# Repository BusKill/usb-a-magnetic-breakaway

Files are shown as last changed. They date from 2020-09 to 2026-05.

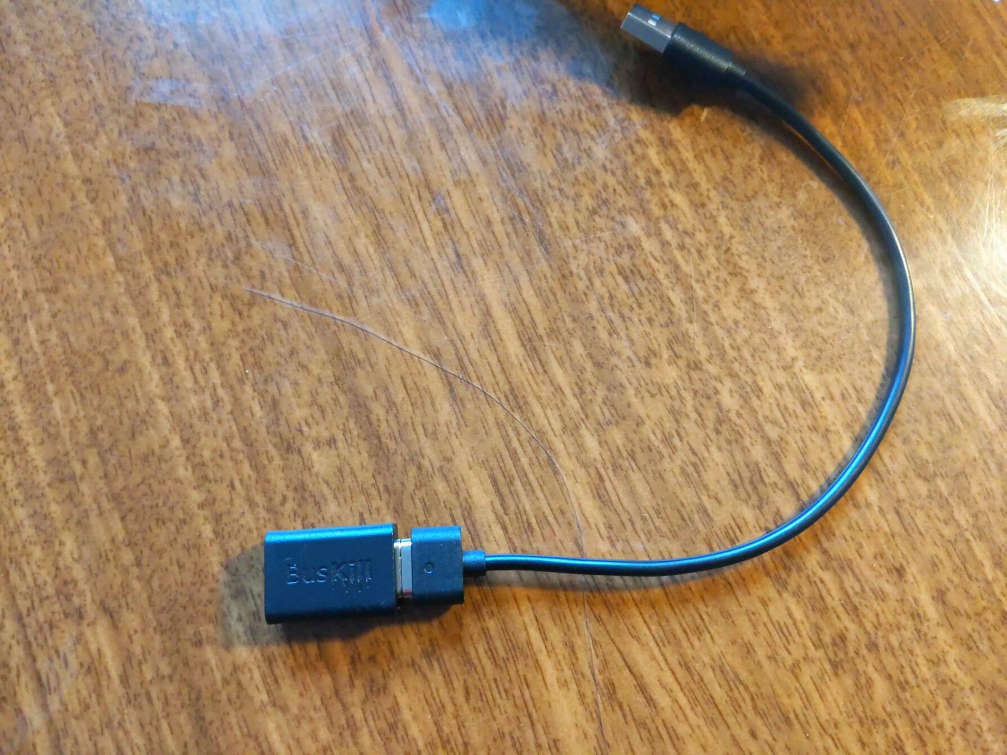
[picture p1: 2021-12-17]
supplier/shenzen_qh_industrial_co/2021-12-04/202112_buskill_sample1a.jpg

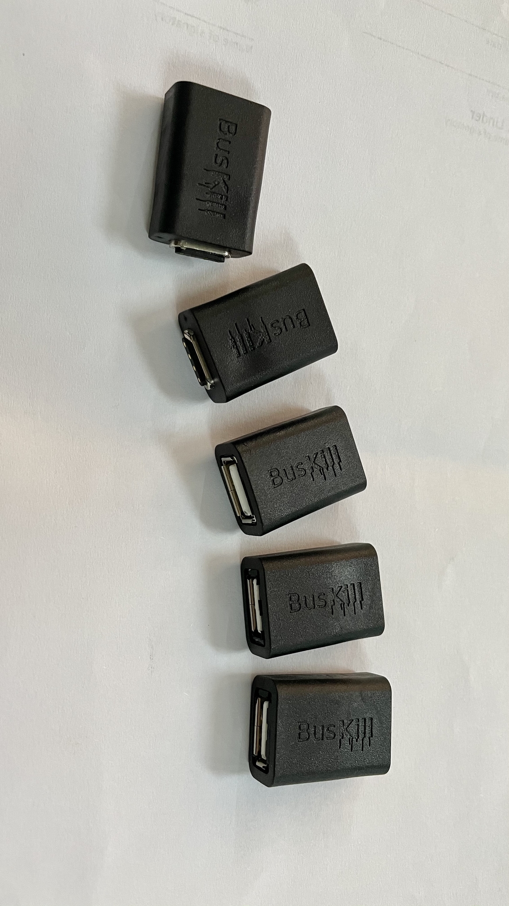
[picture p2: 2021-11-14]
supplier/shenzen_qh_industrial_co/2021-11-14/buskill_samples_001.jpg

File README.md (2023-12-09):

# usb-a-magnetic-breakaway

This repo is for documenting and providing the design requirements for an open-source USB-A magnetic breakaway connector used in the BusKill laptop kill cord. This project is a Work In Progress and it welcomes contributors. 

Please see https://github.com/BusKill/usb-a-magnetic-breakaway/issues/2 for a history of the development so far and the latest news on what people are currently working on with regard to the 3D printed version of the case. 

## For More Information

* What is BusKill? https://tech.michaelaltfield.net/2020/01/02/buskill-laptop-kill-cord-dead-man-switch/
* BusKill YouTube https://www.youtube.com/channel/UC5Njxb027m2OmrocrH33oew
* BusKill Crowdsupply https://www.crowdsupply.com/alt-shift/buskill
* BusKill Open Collective https://opencollective.com/buskill
* BusKill Documentation https://docs.buskill.in

If you create your own version, please create a folder and add your assets to the folder. Feel free to document your section content in this Readme following the style by which we have documented ours.

##  What's New?

* Updates to goldfishlaser Version: She is currently filming Part 2 ofthe assembly instructions and working on the final written documentation. Part 1 Video Assembly Instructions: https://youtu.be/HxwEmIUqQ7w?si=xajbAuSA-TxbAlxz

## What's in this Repo?

This repo contains information about the project, CAD files for two versions of the project, and information about a supplier version of the cable. 

### Glossary
To reference our technical terminology check out [glossary.md](https://github.com/BusKill/usb-a-magnetic-breakaway/blob/3cc552533db1436cacee31b77e96ae590389fd92/Glossary.md)

### goldfishlaser Version

This directory contains files for a version built in OpenSCAD by goldfishlaser. It contains documented 3D print files (SCAD and STL), Bill of Materials, and more. See issue#2 for more details.

goldfishlaser Version

Part 1 Video Assembly Instructions: https://youtu.be/HxwEmIUqQ7w?si=xajbAuSA-TxbAlxz
Prototype Assembly Instructions: https://crashxblossom.wordpress.com/2023/07/04/exciting-milestone-in-buskill-usb-a-magnetic-release-open-hardware-project/

#### CAD Files

Directory contains CAD files for the magnetic breakway case if you want to edit the files. *(in development)*

#### Print files

Directory contains 3D print files for the magnetic breakaway case. *(in development)*

#### Engineering drawings

Directory contains engineering drawings for the magnets which you can provide to a manufacturer for the purpose of ordering the magnets for the magnetic breakway.

#### Magnet_and_PP_Vendor_List.ods

File contains a list of manufacturers that sell magnets, pogo pins, and pogo receptors. 

### Leoheck CAD files
(3D printable case, Work In Progress)
This directory contains files are for a version built in FreeCAD by leoheck.  This version uses Yoosoo spring pressure pogo pins,uses aluminium can for pin contacts, and has pressfit voids for cube magnets. This version contains a female USB port. See issue#2 for more details.



## Supplier Version

image of supplier version

Please see https://github.com/BusKill/usb-a-magnetic-breakaway/issues/4 for history on the development of the Supplier Version. 

### digitalAssets

Digital assets relating to supplier version of the BusKill breakaway

### supplier

Other assets relating to the supplier version of the BusKill breakaway

## Contributing

Please see [Contributing to BusKill](https://docs.buskill.in/buskill-app/en/stable/contributing.html) to learn how you can help the BusKill project.

## Attribution

Thank you to the countless individuals and other open-source projects that have contributed to to the BusKill project!

## Press

As seen on PCMag, Forbes, ZDNet, & Tom's Hardware.

## Contact

To contact us via email, please visit:

    https://www.buskill.in/contact/

## License

The contents of this repo are dual-licensed. All code is GPLv3 and all other content is CC-BY-SA.

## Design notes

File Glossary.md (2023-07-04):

# List of Terms
1. [Breakaway End](#Breakway-End)
2. [BusKill Cable](#BusKill-Cable)
3. [BusKill Software](#BusKill-Software)
4. [Jig](#Jig)
5. [Magnetic_Coupler](#Magnetic-Coupler)
6. [Magnetic Release Cord](#Magnetic-Release-Cord)
7. [Pogo Contacts](#Pogo-Contacts)
8. [Pogo Pin](#Pogo-Pin)
9. [Pogo Contact](#Pogo-Contact)
10. [Release End](#Release-End)
11. [USB A](#USB-A)
12. [USB Ejection Event](#USB-Ejection-Event)
13. [USB Insertion Event](#USB-Insertion-Event)

# Breakaway End 
The Magnetic Coupler has two parts. The Breakway end is the part of the coupler that would separate from the laptop, it terminates the cord that is attached to the user. 

# BusKill Cable 
Used to refer to the assembly of a USB, USB Extender Cord, and Magnetic Coupler with a laptop installed and running BusKill software. 

# BusKill Software 
A program that you can install on Linux, MacOS, or Windows that allows you to set up a trigger that occurs with a USB Ejection Event. The trigger could be locking the screen, shutting down the computer, or something else. 

# Jig
A printed piece that is used to stabilize something during assembly. 

# Magnetic Coupler 
The Magnetic Coupler has two parts, the Breakaway End and the Release End. These two parts contain magnets and contacts. The coupler is designed so that when the magnets are in place, the Pogo Pins and Pogo Receptors contact and transfer signal through the coupler. When the Magnets detach, the Pins and Receptors separate and the signal is disconnected causing a USB ejection event.

# Magnetic Release Cord  
*AKA Magnetic Breakaway Cord* 

All of these terms are used to refer to the assembly of a USB A, USB A Extender Cord, and Magnetic Coupler.

# Pogo Contact 
Contacts refers to either the Pogo Pins or the Pogo Recptors. For the Magnetic Coupler to work, the contacts move the data and power from one end of the magnetic coupler to the other so that the USB drive is connected to the Laptop. They're directly wired into the USB Extender Cord.

# Pogo Pin 
The Pogo Pin is a spring loaded pogo pin. It is soldered to a pin of a USB A port and housed in the Release End of the Magnetic Coupler. When it is in contact with a Pogo Receptor on the end of a USB Extender Cord (housed in Breakaway End of the Coupler), signal 

# Pogo Receptor 
The Pogo Receptor is a conductive contact. It is soldered to the wires of a USB Extender Cord and housed in the Breakway End of the Magnetic Coupler. 

# Release End 
The Magnetic Coupler has two parts. The Release end is the part of the coupler that would remain connected to the laptop, it terminates the cord that ends with the USB that is inside the computer USB port. 

# USB A 
USB A is a type of USB connection. It's the type of connection USB drives use. 

# USB Ejection Event 
What happens when you remove a USB drive from a computer's USB port (or otherwise interrupt the connection, such as with a magnetic coupler) and the computer begins the process of recognizing the connection has terminated.

# USB Extender Cord 
*AKA USB Extension Cable*

The USB Extender Cord is a cord that has a USB female port on one end and a USB at the other end. In the BusKill project, this must necessarily be a Data cord, because the project requires a USB data connection. 

# USB Insertion Event 
What happens when you insert a USB drive into a computer's USB port and the computer begins a process of recognizing the device and establishing a connection.

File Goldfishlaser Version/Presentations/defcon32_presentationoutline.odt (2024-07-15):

BusKill Defcon32 Demo Lab Outline

I. Introduction (2 mins)
  - Who is BusKill?
  - Project Goal
  - Project Rationale
II. Get to know the audience (2 mins)
  - Raise hand if
    - Have ever heard of BusKill
    - Have a 3D printer
    - Use Kali? Use QubesOS? Use Tails?
III. Software Capabilities (5 mins)
  - Lock screen / Shutdown (less than 1 min)
  - Luks Header Shredder (1 min) forensically proven with bulk extractor
  - Qubes
  - Limitations
IV. Hardware Requirements (3 mins)
  - Establishes physical security from computer to person
  - Disconnects usb easily, but not too easily
  - Able to dissemble for inspection
  - Doesn’t block neighboring ports
V. Supplier Version (1 min)
  - Components list
  - Where to find in Repo
VI. 3D-Printed Version (2 mins)
  - Components list
  - Where to find in Repo
  - Demo
VII. Hardware Development History and Philosophy (10 mins)
        - Parametric design in OpenSCAD
        - Milestones
            - Choosing parts (considerations for pogo pins, receptors, usbs)
            - Trying to splice it, frying the USB drives
            - The magnets (hexagonal, Nstrength, disc/cube)
        - Constraints
        - OpenSCAD code tour
VIII. How to help and FAQ (6 mins)
  - Build it
  - Make the case smaller
  - Make assembly easier
  - Identify cheaper and more easily sourced components
  - Make the code more parametric

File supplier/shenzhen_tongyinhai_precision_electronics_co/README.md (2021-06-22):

https://sztyhtech.en.alibaba.com/company_profile.html

    https://sztyhtech.en.alibaba.com/product/60833583652-821299794/2019_New_Product_Frosted_Aluminium_Alloy_Fast_Charging_Magnetic_Adapter_For_Android_Type_C.html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
    https://sztyhtech.en.alibaba.com/product/60835405273-821299794/Tongyinhai_USB_Cable_3_1_Type_C_Male_to_TYpe_C_Female_Magnetic_Adapter.html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
    https://sztyhtech.en.alibaba.com/product/60834397314-821299794/Tongyinhai_New_Product_Aluminum_Alloy_Fast_Charging_Magnetic_Adapter_3_In1_For_Android_Ios_Type_C.html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

See also https://github.com/BusKill/usb-a-magnetic-breakaway/issues/4

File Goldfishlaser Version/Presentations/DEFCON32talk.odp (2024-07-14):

## Open Hardware Design for BusKill Cord

Presented at DEFCON32 Demo Lab by Melanie Allen AKA @goldfishlaser

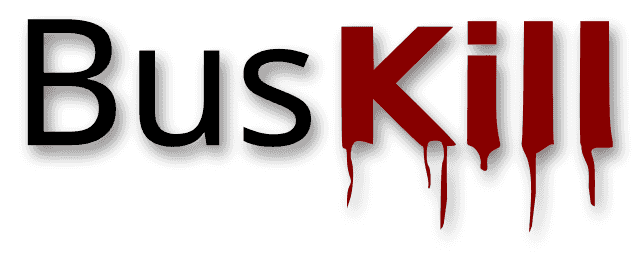
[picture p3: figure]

## Who is ?

Founder

Michael Altfield <michaelaltfield.net>

Lead 3D-Printing Developer

@goldfishlaser

Melanie Allen

<mnallen.net>

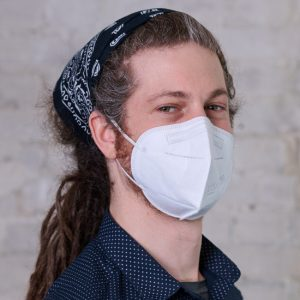
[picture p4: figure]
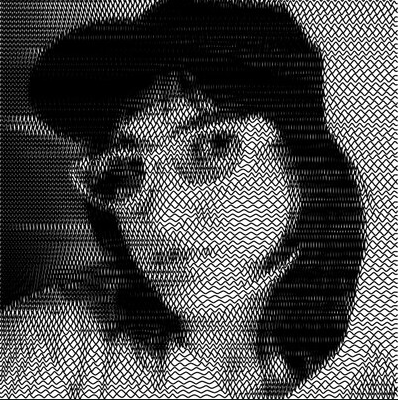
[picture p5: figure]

Contributors (https://docs.buskill.in/buskill-app/en/stable/attribution.html)

Sam <youtube.com/@samxplogs>

Steven Johnson <linkedin.com/in/sj2019/>

Jacob Neplokh <jacobneplokh.com/>

François Marier <fmarier.org/>

Cyberkryption <github.com/cyberkryption>

Links

@BusKill@mastodon.social

https://docs.buskill.in

## Project Goal

- Create a design for BusKill that is suitable for decentralized, home lab manufacture using 3D printing and easily sourced parts to avoid interdiction for high risk individuals such as journalists, activists, and whistleblowers.

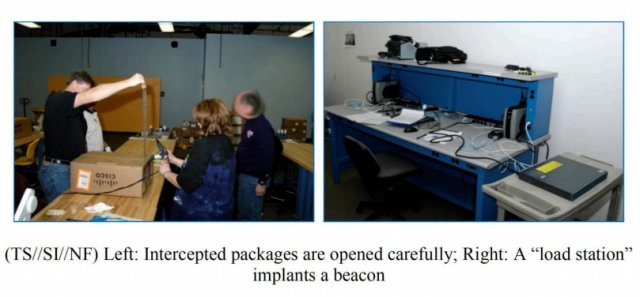
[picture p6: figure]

In 2013, TAO infected 85,000 computers/routers, and they were targeting to increase that to millions

(Source (https://web.archive.org/web/20240625190203/https://www.washingtonpost.com/world/national-security/us-spy-agencies-mounted-231-offensive-cyber-operations-in-20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))

## Project Goal

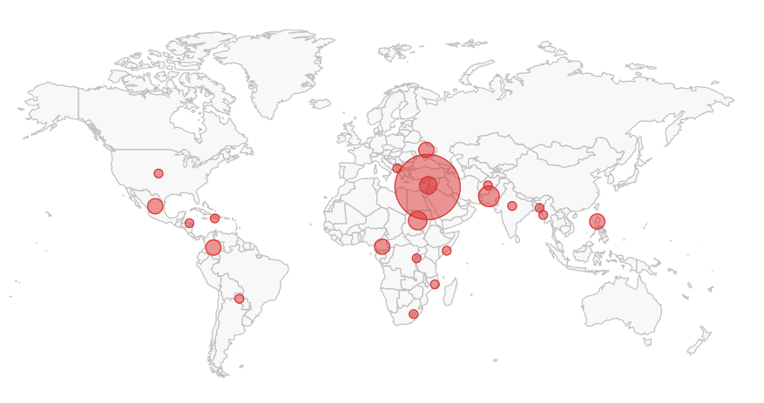
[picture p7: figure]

140 Journalists and Media Workers killed between 2023 and 2024 / Motive Confirmed or Unconfirmed

(Source (https://cpj.org/data/killed/2024/?status=Killed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))

## Purpose

- Allow high risk individuals a method to quickly secure sensitive information when separated from their laptops

## BusKill Software Capabilities

  Lock the computer

perhaps a screencap of Sam's video showing the windows shutdown

## BusKill Software Capabilities

  Shut down the computer

## BusKill Software Capabilities

  Shred your keys

perhaps a hexdump showing random data, or just the featured image from the "luks header shredder" article. Or, if you can do video, the 5.2 second video showing the actual self-destruct (from the article) https://www.buskill.in/luks-self-destruct/

## Qubes

## BusKill Hardware Requirements

- Be able to build in the home
- Be inspectable
- Not block other USB ports
- Separate easily, yet not have false positives

## Manufactured Version

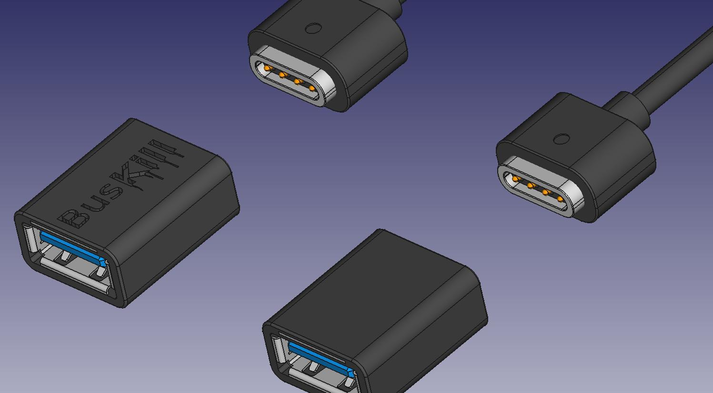
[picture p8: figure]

## 3D-Printed Version Demo

## 3D-Printed BusKill Diagram

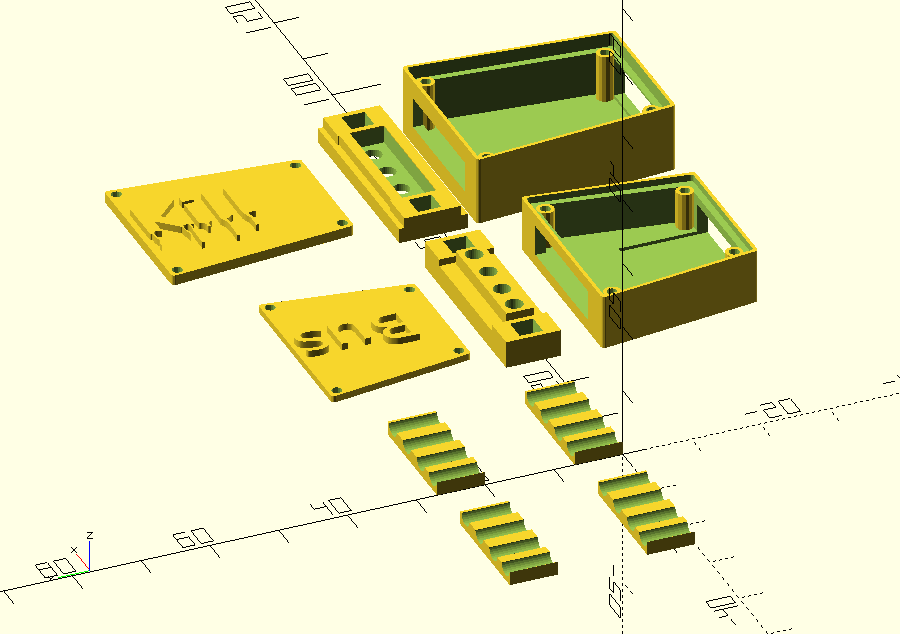
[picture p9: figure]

## Hardware Development Philosophy

- Short history of development
- Link to the repo
- Explain the file and how to edit it

## How you can help – 3D-printing

- Make one
- Improve it
  - The more compact the design, the better
  - The cheaper the design, the better
  - The more parametric the design, the better

## How you can help - Software

- Develop more self-destruct triggers:
  - Veracrypt
  - FileVault
  - Bitlocker

## References

- BusKill web site
- BusKill docs
- BusKill repo
- BusKill USB-A repo
- LUKS shredder blog post

## Questions? Comments?

@BusKill@mastodon.social

https://docs.buskill.in

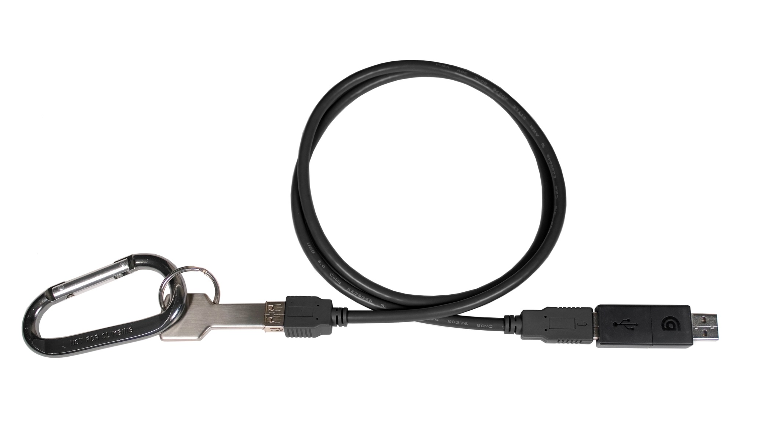
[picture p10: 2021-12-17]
digitalAssets/2021-09_cs_prototype/2021-09_buskill_cs_prototype_connected1.jpg

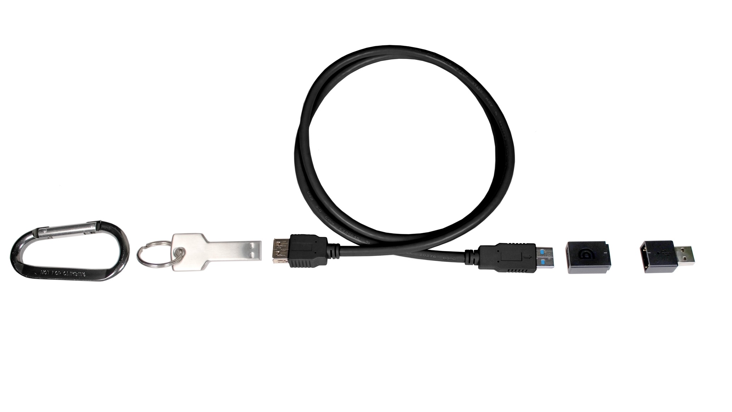
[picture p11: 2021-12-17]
digitalAssets/2021-09_cs_prototype/2021-09_buskill_cs_prototype_separate1.jpg

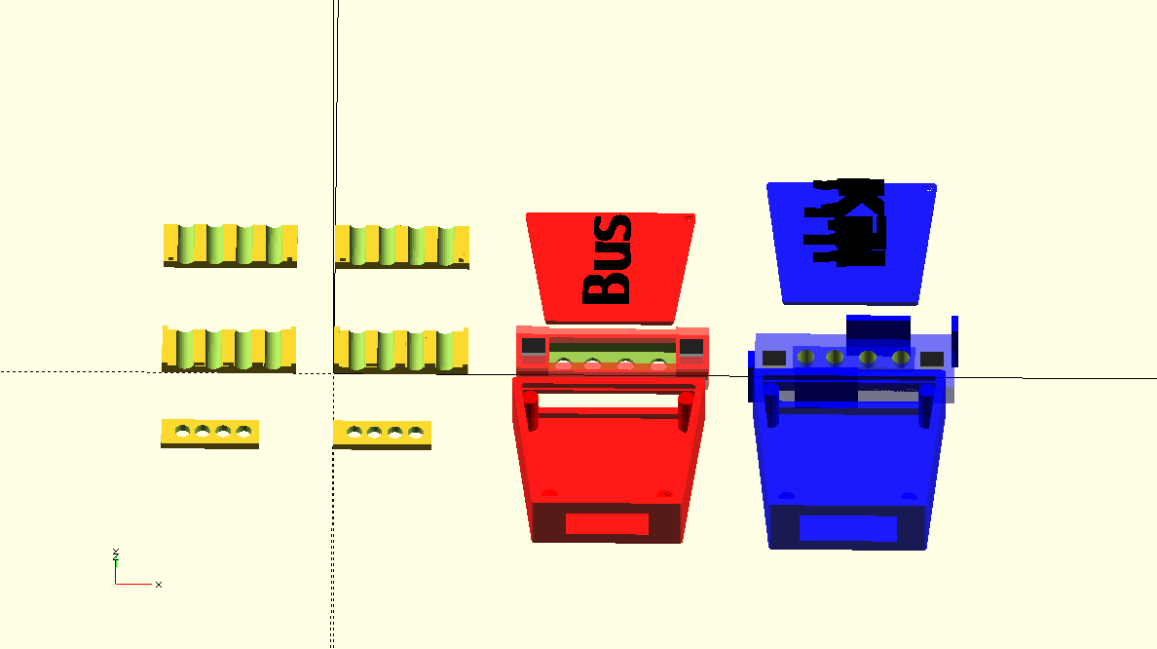
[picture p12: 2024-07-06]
Goldfishlaser Version/CAD Files/usbamagb_v03.9.png

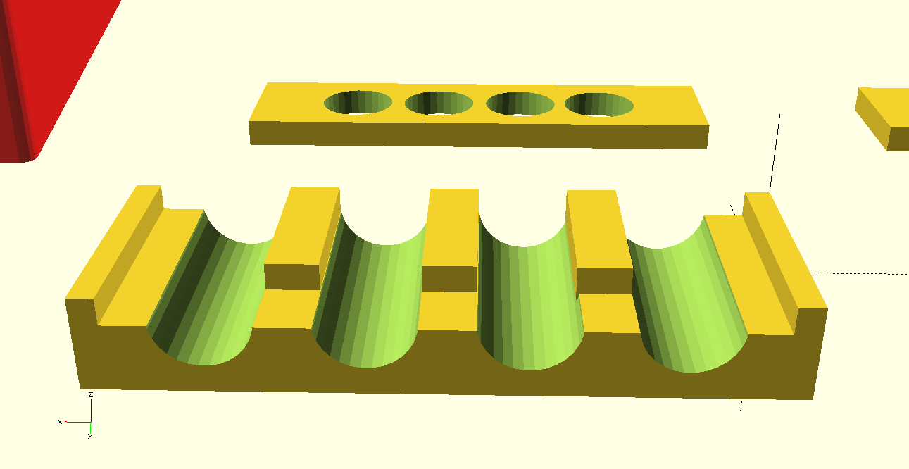
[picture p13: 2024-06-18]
Goldfishlaser Version/CAD Files/jigdetails.png

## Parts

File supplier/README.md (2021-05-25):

This dir has files releated to our attempts to find a supplier for manufacturing the USB-A magnetic breakaway adapter/cable.

For more info, see:

 * https://github.com/BusKill/usb-a-magnetic-breakaway/issues/4

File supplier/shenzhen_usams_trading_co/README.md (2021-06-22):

https://usams.en.alibaba.com/company_profile.html

https://usams.en.alibaba.com/product/1600160439088-812685980/USAMS_AU13_Fast_Charging_Adapter_PD_Magnetic_Type_C_to_Type_C_Adapter_100W.html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

See also https://github.com/BusKill/usb-a-magnetic-breakaway/issues/4

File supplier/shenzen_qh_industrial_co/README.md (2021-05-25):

Links
 * https://mold-parts.en.alibaba.com/?spm=a2700.12243863.0.0.38403e5fWBksNs
 * http://www.pogopin-connectors.com/

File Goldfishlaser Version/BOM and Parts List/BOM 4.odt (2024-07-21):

V 04 Bill of Materials

Open-source USB-A magnetic breakaway connector used in the BusKill laptop kill cord

This BOM is in progress

Component | Base QTY | Link (if applicable)
USB male | 1 | https://amzn.to/43tGNuv
USB female (10 mm) | 1 | https://amzn.to/43tGNuv
Pogo receptors | 4 | https://www.mouser.com/ProductDetail/Mill-Max/3024-0-01-15-00-00-03-0?qs=oyhNEzdnFLo7R2sYdNBgsw%3D%3D
Pogo pins Working height: | 4 | Option 1: https://www.digikey.com/en/products/detail/mill-max-manufacturing-corp/7973-0-15-20-77-14-11-0/10197225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 Option 2: https://www.mouser.com/ProductDetail/Mill-Max/7973-0-15-20-77-14-11-0?qs=%252B6g0mu59x7KQy9JOdoVaiw%3D%3D
3D printed release | 1 | Goldfishlaser Version/CAD Files/intermediary design files/usbamagb_v04.0.stl
3D printed breakaway | 1 | Goldfishlaser Version/CAD Files/intermediary design files/usbamagb_v04.0.stl
1/8” Cube Magnets | 8 | https://www.kjmagnetics.com/proddetail.asp?prod=B222

Estimated Cost Per Unit (without bulk price discounts)

USB Male = .14

USB female = .14

4 x pogo receptors = 4 x .32

4 x pogo pins = 4 x 1.17 (digikey)

or 4 x 1.27 (mouser)

Plastic = 13.76g / 4.61 meters = $8.76

8 x magnets = 8 x .18

USB Extension cord = $8

USB = $10

caribiner = $.80

Total =

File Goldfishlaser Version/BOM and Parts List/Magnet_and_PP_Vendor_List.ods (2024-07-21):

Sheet: Magnets
Prototype Version | Name of Vendor | URL of product page | MOQ | Offer sample service? | Price/magnet | Sizes available (if relevant) | Comments
 |  | Cube magnets
Version >= v.3 | K&J Magnets | https://www.kjmagnetics.com/proddetail.asp?prod=B222 | 1 | N/A | 0.18 | 1/8” | Price/magnet decreases with volume size – Latest Prototype uses these – N52 gold plated may be even better
 |  | Disc magnets DO NOT USE TOO WEAK
Version 2 =< v.2.3.8 | MANHXSCY | https://www.aliexpress.us/item/2251832608106847.html | 100 | no | 0.08 | 4x3 | DO NOT USE – TOO WEAK No longer available at URL - 100pcs Neodymium N35 Dia 4mm X 3mm Strong Magnets Tiny Disc NdFeB Rare Earth For Crafts Models Fridge Sticking magnet 4x3mm
Not used | MANHXSCY | https://www.aliexpress.us/item/2251832608138260.html?gatewayAdapt=glo2usa | 50 | no | 0.175 | 5x4 | No longer available at URL - 50pcs Neodymium N35 Dia 5mm X 4mm Strong Magnets Tiny Disc NdFeB Rare Earth For Crafts Models Fridge Sticking magnet 5x4mm
 | K&J Magnets | https://www.kjmagnetics.com/proddetail.asp?prod=D101-N52 | 100 | N/A | 0.14 | 1/16" dia. x 1/32" thick
 |  | Hex magnets
 | Skyup Magnetics (Ningbo) Co., Ltd. | https://www.alibaba.com/product-detail/12-Years-Experience-factory-producing-rare_62153270553.html | 1 | N/A | $0.02-$0.60 | any
 | Xiamen Balin Magnetic Materials Co., Ltd. | https://www.alibaba.com/product-detail/Powerful-rare-earth-hexagon-neodymium-magnet_62113152666.html | 1 | N/A | $0.05 - $0.50 | any
 | Hangzhou Shengshideng Magnetics Co., Ltd. | https://www.alibaba.com/product-detail/14-Years-Experience-factory-producing-neodymium_60745639237.html | 1 | N/A | $1.00 - $10.00 | any
Version 1 | Dongguan Hj Tech Co., Ltd. | https://www.alibaba.com/product-detail/Hot-Sale-Strong-Electric-Custom-Shape_62489784248.html | 1000 | Yes | $0.03 | any | Placed order for 8 magnets of two sizes. September 9, received order October 10 The stated production time is 15-20 days, and the express delivery time is 7-9 days. There was a small delay, possibly due to holiday. (oops – didn’t realize this shop had a MoQ of 1000, but the customer service was great, and the person I worked with says I and others can order lower quantities if desired)

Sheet: Pogo Pins
Prototype Version | URL of product page | MOQ | Offer sample service? | Price/pin | Type | Comments
Version >= v.2.3.9 | https://www.digikey.com/en/products/detail/mill-max-manufacturing-corp/7973-0-15-20-77-14-11-0/10197225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 | 1 | N/A | $1.13 | 2.66mm STANDARD SPRING-LOADED PIN Contact Spring Through Hole, Solder Cup | Price decreases with order quantity; must pay shipping
Version =< v.2.3.8 | https://www.digikey.com/en/products/detail/mill-max-manufacturing-corp/0947-0-15-20-77-14-11-0/7402798 | 1 | N/A | $0.97 | 7.58mmSTANDARD SPRING-LOADED PIN CONTACT SPRING LOADED SLDR CUP | Price decreases with order quantity
Version =<v3.9 | https://www.alibaba.com/product-detail/Circular-SMD-Contact-Pad-3-0_62437659039.html | 500 | yes | $0.07 | 3.00mm radius contact pad, 2.00mm height, target pin | Ordered 11/28/2020 Received 12/16/2020
Version 4.0 | https://www.mouser.com/ProductDetail/Mill-Max/3024-0-01-15-00-00-03-0?qs=oyhNEzdnFLo7R2sYdNBgsw%3D%3D | 1 | N/A | $0.32 | Circuit Board Hardware - PCB Spring-Loaded Target Contact with Flat Face | Price decreases with order quantity; must pay shipping
Version >= v.2.3.9 | https://www.mouser.com/ProductDetail/Mill-Max/7973-0-15-20-77-14-11-0?qs=%252B6g0mu59x7KQy9JOdoVaiw%3D%3D | 1 | N/A | $1.27 | Circuit Board Hardware - PCB Spring-Loaded Pin with Solder Cup Termination | Price decreases with order quantity; must pay shipping

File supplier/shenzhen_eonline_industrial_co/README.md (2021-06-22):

https://eonline.en.alibaba.com/company_profile.html

    https://eonline.en.alibaba.com/collection_product/magnetic/9.html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
    https://eonline.en.alibaba.com/product/1600185201457-814306045/100W_Usb_C_To_Type_C_Magnetic_Adapter_Fast_Charging_Usb_Type_C_Magnet_Converter_Magnetic_Cable_Right_A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
    https://eonline.en.alibaba.com/product/1600153055891-814306045/5A_Type_C_USB_Cable_Convert_Plug_Magnetic_Cable_Adapter_Magnetic_Charger_Cable_Connector_Mobile_Phone_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
    https://eonline.en.alibaba.com/product/1600096650403-814306045/Eonline_3A_Type_C_Adapter_Magnetic_Charger_USB_Connector_for_Samsung_iPhone_Xiaomi_Huawei_Phone_Charge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
    https://eonline.en.alibaba.com/product/1600212643148-816609648/EONLINE_100W_Magnetic_Adapter_USB_Type_C_with_Cable_For_Macbook_20_pin_USB_High_Speed_Magnet_USB_C_Con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
    https://eonline.en.alibaba.com/product/1600207741686-816609648/9Pin_Magnetic_USB_C_Adapter_Type_C_Connector_PD_100W_Quick_Charge_480Mdps_Magnet_Type_C_Connector_For_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
    https://eonline.en.alibaba.com/product/1600207762443-816609648/EONLINE_24pin_Compatible_for_Thunderbolt_3_Magnetic_Adapter_40Gbps_Data_5K_100W_and_20V_5A_Charge_for_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
    https://eonline.en.alibaba.com/product/1600207696312-816609648/EONLINE_Magnetic_Type_USB_C_Adapter_PD_Charger_and_Data_Transmision_10Gbp_s_USB3_1_Type_C_Power_Delive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
    https://eonline.en.alibaba.com/product/1600265950984-816609648/EONLINE_24_Pins_Magnetic_USB_C_Adapter_Type_C_Connector_PD_100W_Quick_Charge_10Gbp_Data_4K_HD_Hub_for_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

See also https://github.com/BusKill/usb-a-magnetic-breakaway/issues/4

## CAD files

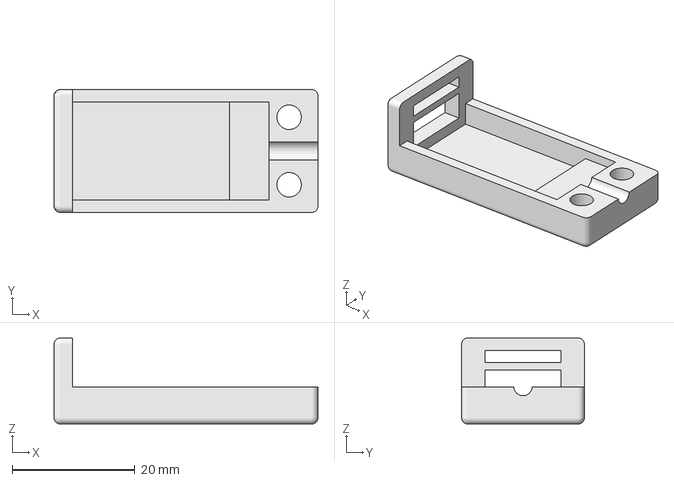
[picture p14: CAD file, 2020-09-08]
Goldfishlaser Version/CAD Files/Shell_Assembly.FCStd
43.0 x 20.0 x 14.0 mm

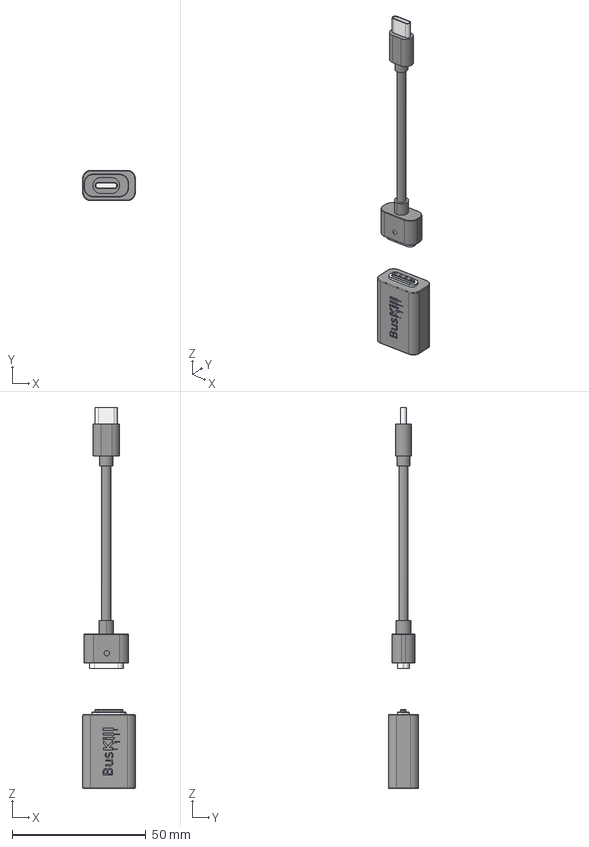
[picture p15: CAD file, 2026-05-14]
digitalAssets/cad/cable/AS-BKC-CAB-001_short.FCStd
19.7 x 11.3 x 142.3 mm
pogo pin
MAGNET - 2
Housing - 2
pogo pin001
pogo pin002
pogo pin003
In mold
Out mold
cable
50u_pin002
housing
overmold001
usb
50u_pin003
50u_pin004
50u_pin001
magnet

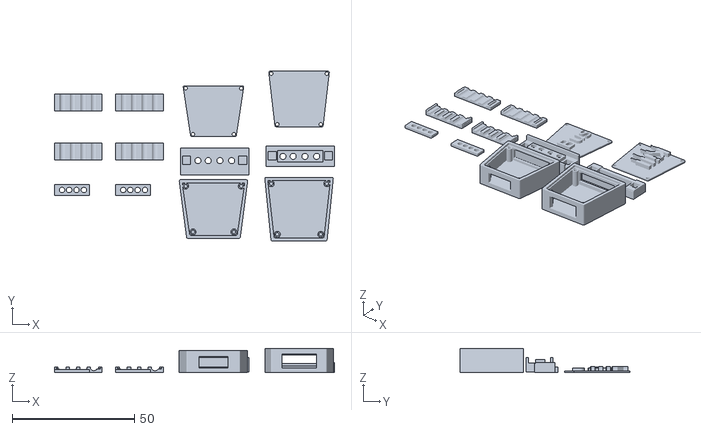
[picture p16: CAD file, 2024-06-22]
Goldfishlaser Version/CAD Files/intermediary design files/usbamagb_v03.1b.stl
114.5 x 69.4 x 10.0

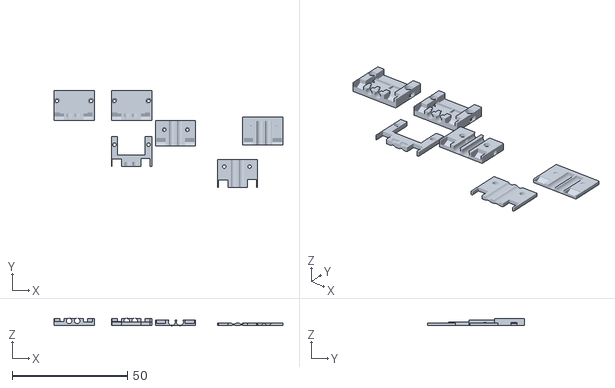
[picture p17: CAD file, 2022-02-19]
Goldfishlaser Version/CAD Files/intermediary print files/magnetic_release_v0.8.stl
99.5 x 42.0 x 3.23

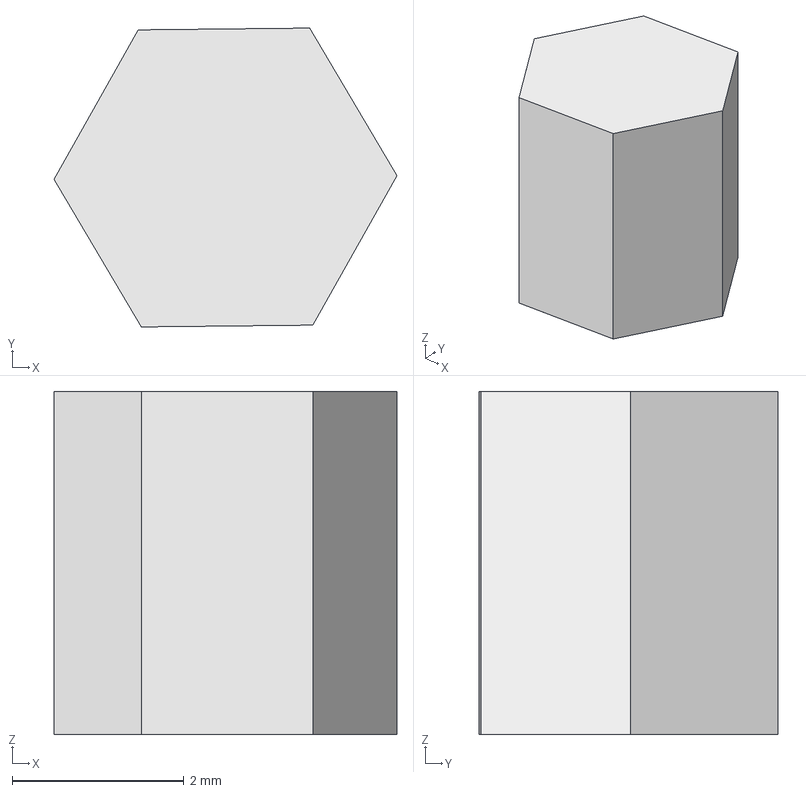
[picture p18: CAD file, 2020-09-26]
Goldfishlaser Version/CAD Files/Magnet_2mm_4mm.fcstd
4.00 x 3.49 x 4.00 mm

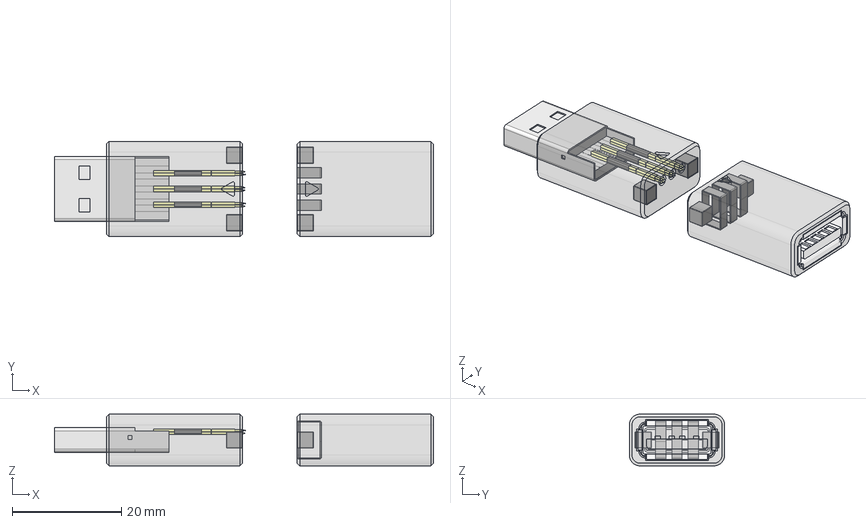
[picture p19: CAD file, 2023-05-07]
Leoheck CAD files/Housing-v0.1-leoheck.FCStd
69.5 x 17.5 x 9.50 mm
Magnet_Cube x 8
Housing-USB_Male x 2
Pogo-Pin x 6
Pogo-Pin001 x 6
Pogo-Pin002 x 6
Pogo-Pin003 x 6
HeatShrink x 6
usb_inside v5_mod x 2
USB v6 Shell Mod x 2
Housing-USB-Male-Guts x 2
Housing-USB_Female x 2
usb3_mod x 2
Pogo-Contact x 6

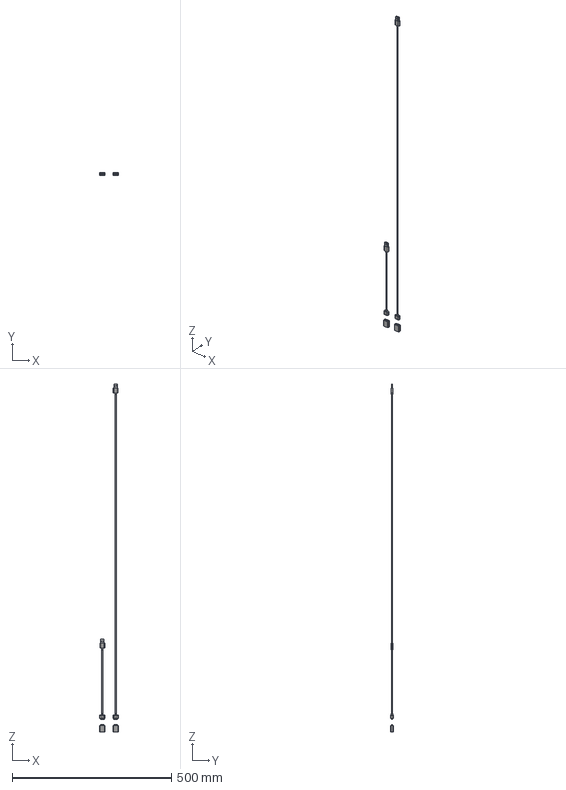
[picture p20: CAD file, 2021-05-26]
supplier/shenzen_qh_industrial_co/2021-05-26/4Pin_2.54mmPH_runway_male_female_magnetic_connector_with_USB-Female_adapter.stp
59.7 x 9.34 x 1091.2 mm
pogo pin x 8
MAGNET - 2 x 2
Housing - 2 x 2
In mold x 2
Out mold x 2
50u_ PIN (6) (4) x 8
MAGNET x 2
Housing (2) x 2
overmold x 2
usb_20_step x 2
Cable1
Cable2

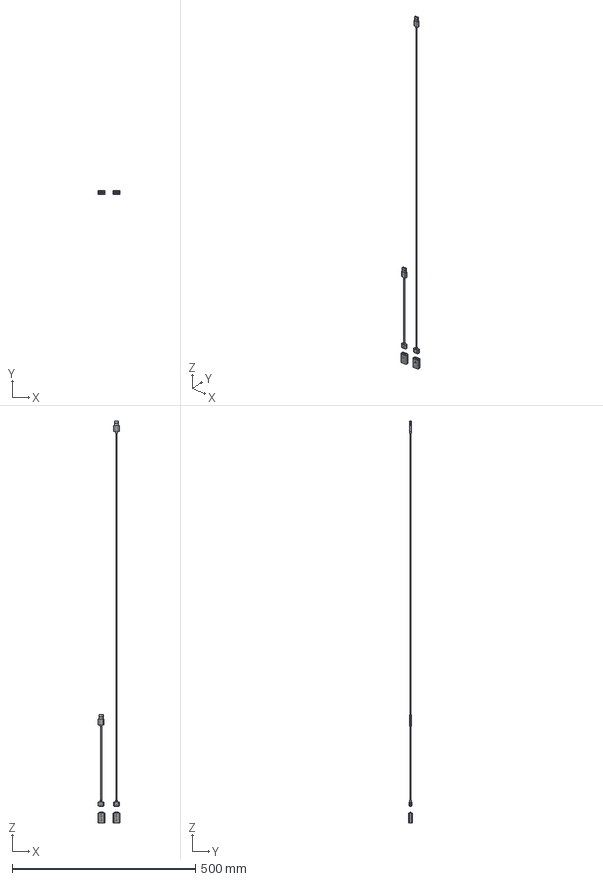
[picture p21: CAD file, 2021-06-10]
supplier/shenzen_qh_industrial_co/2021-06-10/4Pin_2.54mmPH_runway_male_female_magnetic_connector_with_USB-Female_adapter_20210609.stp
60.7 x 11.3 x 1096.3 mm
pogo pin x 8
MAGNET - 2 x 2
Housing - 2 x 2
In mold x 2
Out mold x 2
Cable1
Cable2
10.7mmH female pin x 8
Housing (2) x 2
buskill_cable__overmold_20210603 _1__stp x 2
USB 2.0 Female SMT x 2

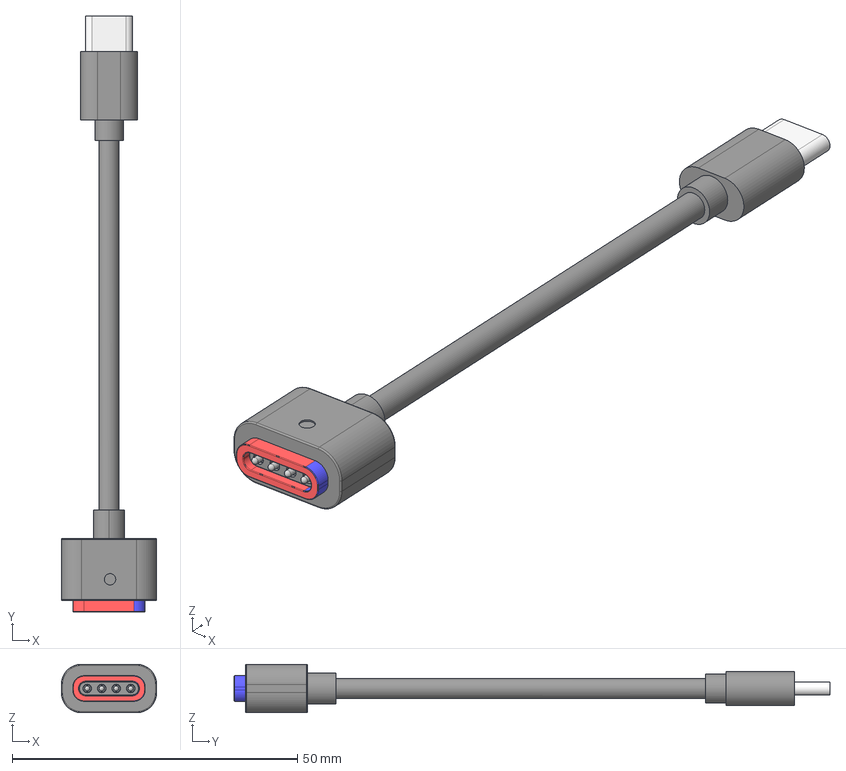
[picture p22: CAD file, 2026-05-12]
supplier/shenzen_qh_industrial_co/2025-02/4Pin_2.54mmPH_runway_magnetic_connector_TYPEC.stp
16.7 x 104.5 x 8.50 mm

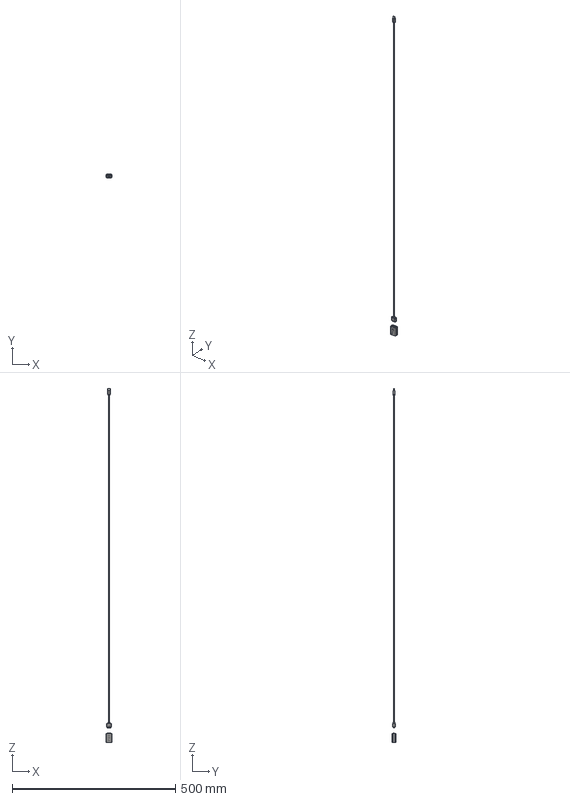
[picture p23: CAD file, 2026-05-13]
digitalAssets/cad/cable/AS-BKC-CAB-001.FCStd
19.7 x 11.3 x 1084.3 mm
pogo pin004
MAGNET - 003
Housing - 003
pogo pin005
pogo pin006
pogo pin007
In mold001
Out mold001
cable
usb
50u_pin003
overmold001
housing
50u_pin001
50u_pin004
magnet
50u_pin002

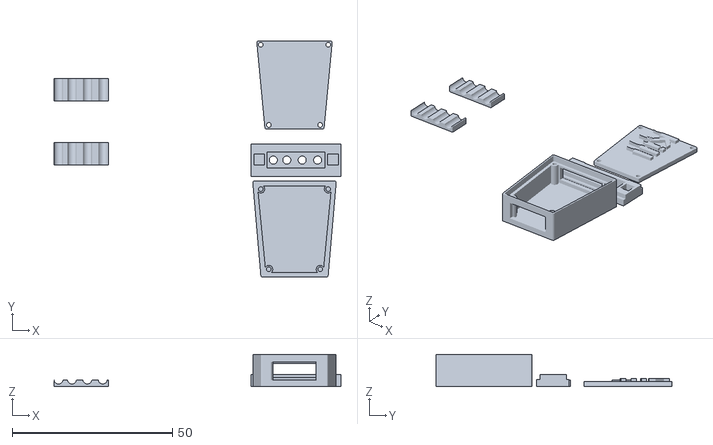
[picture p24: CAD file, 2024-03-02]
Goldfishlaser Version/CAD Files/intermediary design files/breakaway_v03.9.2.stl
89.5 x 73.7 x 10.0

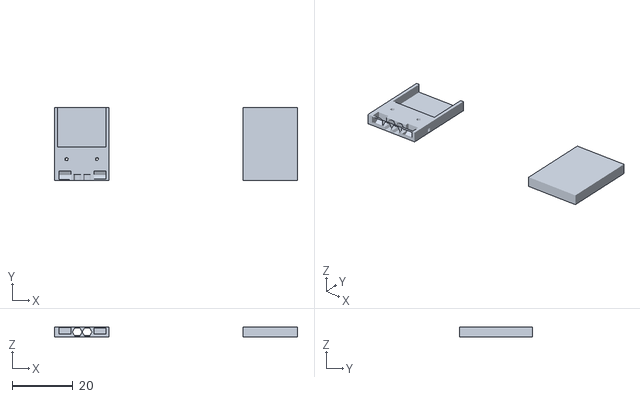
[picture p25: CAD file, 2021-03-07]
Goldfishlaser Version/CAD Files/intermediary print files/magnetic_release_0.7.stl
80.0 x 24.0 x 3.25

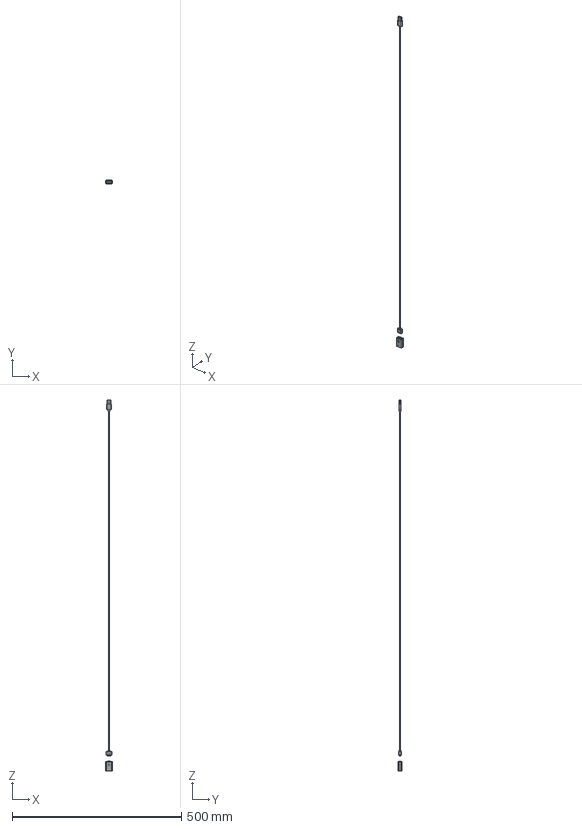
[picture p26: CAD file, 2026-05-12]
digitalAssets/cad/cable/AS-BKA-CAB-001.FCStd
19.7 x 11.3 x 1096.3 mm
pogo pin004
MAGNET - 003
Housing - 003
pogo pin005
pogo pin006
pogo pin007
In mold001
Out mold001
Cable1
usb
50u_pin003
overmold001
housing
50u_pin001
50u_pin004
magnet
50u_pin002

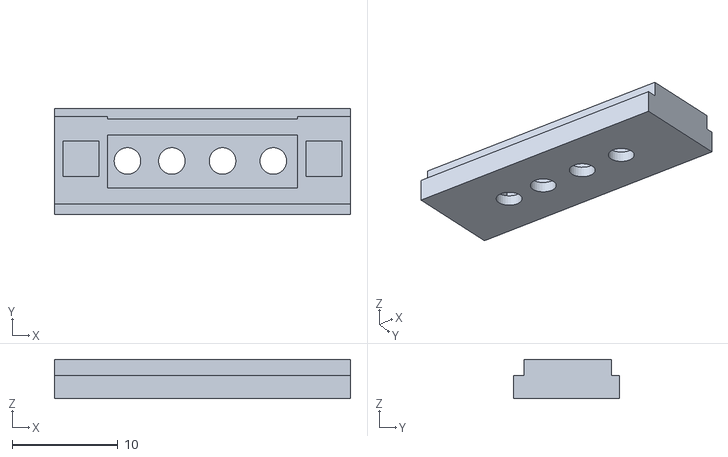
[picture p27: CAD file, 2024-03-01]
Goldfishlaser Version/CAD Files/intermediary design files/breakawayface_v03.9.2.stl
28.0 x 10.0 x 3.70

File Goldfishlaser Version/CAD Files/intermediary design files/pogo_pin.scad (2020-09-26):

$fn=20;
/*
  Pogo Pin Serial Adaptor (Customisable)
  Author: Brian Khuu 2019
  
  This is similar to https://hackaday.com/2017/08/04/pogo-pin-serial-adapter-thing/
  But is fully 3D printed without need for PCB. This may be useful for Arduino serial adaptors.
  
  I used P100-E2 probes for this
*/

// Designed For Printer Nozzle
printer_nozzle=0.4;

// Base Thickness
base_thickness = 0.1;

/* probe pin spec */
ppext = 6.8; // Probe extention length
ppbody = 14; // Body of the probe
ppdia = 1.5; // probe pin diameter

ppdiatol = 0.6; // tolerance for fitting
ppinset = 2.5;

ppdiaoutset = ppext-ppinset; // How far to space out to allow for side fits
echo(ppdiaoutset);

/* Castellated Module Pin Spacing and count */

// Pin Count
ppc = 2;

// Pin Spacing
pps = 2.54;

// PCB Thickness
pcb_thickness = 1.1; // 1mm Open Log Clone

// PCB Probe Offset
pcb_probe_offset = 1.3;

/* Clip */
clip_tab = 5; // Clip tab to more easily open the clip

/* pcb */
pcb_h = 2; // pcb thickness

/* calc */
boxx = ppc * pps + ppdia;
boxy = 2 + ppbody + ppdiaoutset;
boxh = base_thickness+pcb_probe_offset+ppdiatol+5;

module probe_pin_req()
{
  inset=0;
  translate([0,0,-ppbody])
  union()
  {
    translate([0,0,0])
      cylinder(r1=(ppdia)/2,r2=(ppdia+ppdiatol)/2, h=3);
    translate([0,0,1])
      cylinder(r=(ppdia+ppdiatol)/2, h=ppbody+ppext+1);
    %color("gold") cylinder(r=ppdia/2, h=ppbody);
    %color("silver") translate([0,0,ppbody])
      cylinder(r=ppdia/2, r2=0, h=ppext);
  }
}

module openlog_clone_programmer_jig()
{
  difference()
  {  
    /* Bulk */
    union()
    {
      difference()
      {
        cube([boxx,boxy,boxh]);
        translate([-5, 0, base_thickness+pcb_probe_offset+ppdia*1.5]) 
          cube([ppc * pps+10,ppbody, 5]);
      }
      translate([-(ppdia)/2, ppdiaoutset+7+ppbody/2, 0]) 
        cube([boxx+(ppdia),boxy-(ppdiaoutset+7+ppbody/2), boxh]);
      translate([-(ppdia)/2, ppdiaoutset, 0]) 
        cube([boxx+(ppdia),7, 5]);
    }

    /* Probe Access Cutout */
    translate([-5, ppdiaoutset+7, base_thickness+pcb_probe_offset+ppdia/2]) 
      cube([ppc * pps+10,ppbody/2, boxh]);
      
    /* Module Cutout */
    translate([0, -0.001, base_thickness+ppdia+ppdiatol]) 
      cube([boxx,ppdiaoutset, boxh]);
      
    /* Probe */
    for ( xi = [0 : 1 : ppc-1] )
    {
      translate([ppdia/2+pps/2+pps*xi, 0, base_thickness])
      union()
      {
        translate([0, ppdiaoutset, pcb_probe_offset+ppdiatol])
          rotate([90,0,0])
          probe_pin_req();
        
        translate([0, ppdiaoutset, pcb_probe_offset+ppdiatol])
          rotate([180,0,0])
            translate([0, (ppdiaoutset)/2, 0])
              cube([ppdia+ppdiatol,(ppdiaoutset),ppdia+1], center=true);
      }
    }
    
    /* Wire Guide (To solder onto the probe) */
    for ( xii = [0 : 1 : ppc-1] )
    {
      translate([ppdia/2+pps/2+pps*xii, boxy+1, base_thickness+ppdia+1.5+pcb_probe_offset+ppdiatol])
        rotate([95,0,0])
          cube([2,2.5,20],center=true);
    }
  }
}

openlog_clone_programmer_jig();

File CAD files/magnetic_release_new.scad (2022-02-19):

/*                      
Buskill USB-A Magnetic breakaway Shell Assembly     
GNU General Public License v3.0 
Author: Melanie Allen
*/

/*
Description

BusKill is a Dead Man Switch triggered when a magnetic breakaway is tripped, severing a USB connection. This design is for USB-A.

The user will have a USB, a USB extension cable, and the magnetic breakaway. 

The magnetic breakaway device should be sized so that it doesn't block other USB ports on the user's computer.

The "breakaway" receives the USB from the USB cable with a female USB port. It is in four parts, the base, two middle pieces, and the lid. It contains 4 pogo pins and 2 magnets. It separates from the release when the cord is pulled.

The "release" plugs into the computer with a male USB. It is in three parts, the base, the middle, and the lid. It contains 4 pogo receptors and 2 magnets.

The middle pieces are created in order to stabilize the pogo pins and magnets from the top and bottom pieces to keep them from interfering with each other.

When the magnets on the breakaway and release connect, the pogo pins and pogo receptors must meet and establish the USB connection.

The breakaway and release plugs must be designed asymmetrically to prevent the connection from happening the wrong way. 

The case must be designed so that the user can completely dissemble it and ensure there has been no tampering. No glue must be required. The base and lid connect together with tiny screws and embedded nuts. There will be a middle wall piece for both ends that separates top and bottom components.

The magnets are a custom hexagonal shape so that they can connect at the flat surface and be held in place by the plastic without requiring glue. The engineering document is available on the repo.

docs.buskill.in
buskill.in
*/

/* * * * TO DO * * * */
//figure out exact shapes so that magnets and pogos are secured during assembly
//properly define variables instead of kludging values

module main(){

zpascifier = 0.02; //value to prevent z-fighting

/* * Magnet * */

//Download magnet2.stl from repo into the same folder as this .scad file

magnet_distance=12.5;

module magnet(){
    color( "SlateGrey", 1.0 )
    rotate([0,90,0]){
        import("magnet2.stl");
    }
}
//magnet();

/* * Notch * */

//The notch should extrude from the release, and cut into the breakaway so that they can only connect in one orientation.

module notch(){
    color("white"){
        rotate([90,0,0]){
            cylinder($fn = 30, $fa = 30, $fs = 2, .5,.5,.5,$fn=3);
        }
    }
}
//notch();

/* * Pogo Pin * */
    module pogo_pin(){
    color("yellow"){
        rotate([90,0,0]){
            cylinder($fn = 30, $fa = 30, $fs = 2, h=pogo_length, r1=pogo_diameter, r2=pogo_diameter, center = false);
        translate([pogo_distance,0,0]){
            cylinder($fn = 30, $fa = 30, $fs = 2, h=pogo_length, r1=pogo_diameter, r2=pogo_diameter, center = false);
        }
    }
}
}
//pogo_pin();

/* * Screw and Nut * */
s_h=7; // screw length
s_r1=.75; // screw shaft radius
s_r2=2; // screw top radius
n_l=7; //nut channel length
n_h=1.3; //nut height
n_d=14; //distance between nuts

/* * * Create Breakaway * * */
 
 //The "breakaway" receives the USB from the USB cable with a female USB port. It is in two parts, the base and the lid. It contains pogo pins and magnets.

/* * Variables * */

//breakaway base variables
i_h = 17.5; //x
i_w = 2.5; //z
i_d = 24; //y
 
i2_h = 8; //x
i2_w = 0; //y
i2_d = 2.5; //z

//breakaway lid variables
i_l_h =i_h; //z
i_l_w = i_w; //x
i_l_d = i_d; //y

i2_l_h =i2_h; //z
i2_l_w = i2_w; //x
i2_l_d = i2_d; //y

//cut_female variables
cf_h = 19; //the width for some reason
cf_w = 13; //the height 
cf_d = 5.75; // the same as cf_w for some reason... 

//pogo variables
//pogo pins are shaped like a cylinder.

pogo_length=12;
pogo_tip=1.5;
pogo_diameter=1.5;
pogo_distance=3.5+zpascifier; //distance between pins (x=z)

module breakaway_magnet(){
        translate([52.5,-27.17,-5]){
            magnet();
            translate([magnet_distance,0,-zpascifier]){
                magnet();
            }
        }
    }
    //breakaway_magnet();
    
/* *  Build Modules * */
 module cut_female(){
    translate([51,-cf_w,-1.5]){
        cube(size=[cf_h,cf_w,cf_d], center = false);
    }
}
//cut_female();
    module breakaway_base(){
    color("pink", .5){
    difference(){
    rotate([90,0,0]){
        translate([52,0,zpascifier]){
        cube(size = [i_h, i_w, i_d], center = false);   
            }
        }
            translate([57,-24,1+zpascifier]){
cube(size= [i2_h,i2_w,i2_d], center = false);
            }
    }   
}
    };  

//breakaway_base();
module create_breakaway(){
    module subtract_pogo_pin(){
    difference(){
        breakaway_base();
        translate([59.2,-13,1.625]){
            pogo_pin();
        }
    }
}
//subtract_pogo_pin();

    
    module breakaway_add_notch(){
}
//add_notch();

    module breakaway_subtract_magnets(){


    difference(){
        subtract_pogo_pin();
        breakaway_magnet();
    }
}
    

//breakaway_subtract_magnets();

module subtract_cut_f(){

//cut_female();
    difference(){
        breakaway_subtract_magnets();
        translate([0,0,-.7])cut_female();
        
    }
}
//subtract_cut_f();

    module make_screw_tops_breakaway(){    
    module screw_tops_breakaway(){
        cylinder(h=s_h, r1=s_r1, r2=s_r2, center = false);
    }

    module two_screws_tops_breakaway(){
        translate([0,-17,0]){
        screw_tops_breakaway();
    }

    translate([10,-17,0]){
        screw_tops_breakaway();
        }
    }

    translate([56,0,0]){
        two_screws_tops_breakaway(); //for breakaway base
    }

    translate([116,0,0]){
        two_screws_tops_breakaway(); // for breakaway lid
    }
};
//make_screw_tops_breakaway();

    module subtract_screw_tops_breakaway(){
    difference(){
        subtract_cut_f();
        make_screw_tops_breakaway();
    }
}
//subtract_screw_tops_breakaway();

    module make_nuts_breakaway(){
        
  module nut_breakaway(){
    rotate([90,90,0]){
        translate([0,0,0]){
        cube(size=[n_h,n_l,n_h], center = false);
            }
        }
    }
  nut_breakaway(); //make one nut
    translate([n_d,0,0]){
      nut_breakaway(); //make one nut n_d distance from the first nut
    }

}


    module subtract_nuts_breakaway_base(){
        
    difference(){
        subtract_screw_tops_breakaway();
        translate([51,-16.5,1.5]){
            make_nuts_breakaway(); //two nuts
            }
    }
}
subtract_nuts_breakaway_base();
}
//create_breakaway();
part_loc_x=90;

module create_breakaway_lid(){
    
    module breakaway_lid_block(){
            color("red", .5){
    rotate([90,0,0]){
       translate([part_loc_x,0,11.5]){
            cube(size = [i_l_h, i_l_w/2, i_l_d/2], center = false);   
            }
     }
}     
}
//breakaway_lid_block();
screw_depth=-16;
screw_distance=11;
 
        module void(){
        translate([7.5,-13.1,1.625]){
            pogo_pin();
            } //subtract pogo_pin
        translate([.5,-27.17,-5]){
            magnet();
            translate([magnet_distance,0,-zpascifier]){
                magnet();
            } //subtract magnets
        }         
            translate([62,zpascifier,-zpascifier]){
            cut_female(); //subtract usb
            }
              module screw(){
        cylinder($fn = 30, $fa = 30, $fs = 2,h=s_h, r1=s_r1, r2=s_r2, center = false);
        translate([screw_distance,0,0])cylinder($fn = 30, $fa = 30, $fs = 2,h=s_h, r1=s_r1, r2=s_r2, center = false);
    }
  translate([3.5,screw_depth,1]){
        screw();
    }
  
    };
//translate([part_loc_x,0,0]) {void();}
difference(){
    breakaway_lid_block();
    translate([part_loc_x,0,0]) {void();}
}
};
    

//create_breakaway_lid();

module create_breakaway_m(){
    module screw(){
        cylinder($fn = 30, $fa = 30, $fs = 2,h=s_h, r1=s_r1, r2=s_r2, center = false);
        translate([11,0,0])cylinder($fn = 30, $fa = 30, $fs = 2,h=s_h, r1=s_r1, r2=s_r2, center = false);
    }
    
    //block
    module block(){
    color("DeepPink",.55)
    translate([46,-30,0])  rotate([90,0,0]){
            translate([33,0,0]){
                cube(size = [i_l_h, i_l_w/2, i_l_d/2], center = false);
            }
        } 
    } 

    module void(){
        translate([86,-30,-1.2]) pogo_pin();
        translate([86,-30,2.2]) pogo_pin(); //cut pogos    
        
translate([82,-33,-zpascifier]) screw();//cut holes  
            translate([79.5,-45.25,-6]){magnet();
            translate([magnet_distance,0,-zpascifier]){
                magnet();  }}
//cut magnets 
    }
    
        difference(){
        block();
        void();
    
        
    }
    
        //void();
}


/* * * Create Release * * */

//The "release" plugs into the computer with a male USB. It is in two parts, the base and the lid. It contains pogo receptors and magnets.
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

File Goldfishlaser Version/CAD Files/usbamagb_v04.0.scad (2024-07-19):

/*

__________ ____ ___  _____________  __.___.____    .____     
\______   \    |   \/   _____/    |/ _|   |    |   |    |    
 |    |  _/    |   /\_____  \|      < |   |    |   |    |    
 |    |   \    |  / /        \    |  \|   |    |___|    |___ 
 |_______ /______/ /_______  / ___|__ \___|_______ \_______ \
                              \/     \/           \/       \/
                                                  \/       \/   usbamagb_v04.0               

*/
/*                      
Buskill USB-A Magnetic breakaway Shell Assembly     
GNU General Public License v3.0 
Author: Melanie Allen
*/
    

/*
Description

BusKill is a Dead Man Switch triggered when a magnetic breakaway is tripped, severing a USB connection. This code creates a 3D printable file for plastic parts needed to create the magnetic breakaway. 

To assemble a BusKill Dead Man Switch cord you will need: a usb-a extension cord, a usb hard drive capable of being attached to a caribiner, a caribiner, the plastic pieces in this file, a usb female port, a usb male, 4 magnets, 4 pogo pins, 4 pogo receptors, wire, 8 screws, and BusKill software. For full BOM, glossary, and assembly instructions, see the files in the repo.

The magnetic breakway consists of a "breakaway" (blue) and a "release" (red). When the magnets on the breakaway and release connect, the pogo pins and pogo receptors meet and establish the USB connection. When the parts are separated, the USB connection is severed.

The "breakaway" consists of three plastic pieces. The enclosure, the lid, and the face. The face contains areas for two 1/8" cube magnets and pogo receptors. The enclosure allows for the housing of a wire jig, wires and female usb port. The lid screws onto the enclosure with 4 x 1.5-2M screws. 

The "release" consists of three plastic parts. The enclosure, the lid, and the face. The face contains areas for two 1/8" cube magnets and pogo pins. The enclosure allows for the housing of a wire jig, wires, and male usb. The release plugs into the computer. The lid screws onto the enclosure with 4 x 1.5-2M screws.

"Jigs" serve purposes such as housing wires and holding hardware in place during assembly and use. (yellow)

The code in this file is divided into five section: Parameters, Hardware, Breakaway, Release, and Assembly.
Parameters: Should you need to adjust this design to suit the parts available to you, you can tune variables for parts in this section 
Hardware: This section contains modules related to creating areas for magnets, usb, pogo pins, pogo receptors, and jigs. 
Breakaway: This section contains modules related to creating enclosure (lid, body, and face) for the breakaway. 
Release: This section contains modules related to creating the enclosure (lid, body, and face) for the release.
Assembly: This section allows you to call the modules individually or all at once. 

If you're new to openscad, might be helpful to know that numbers representing dimensions are in "mm" units. 

The assembly of the BusKill cord is as follows: (1) attach the caribiner to the usb (2) insert the USB hard drive into the female usb port in the assembled "breakaway" (3) connect the magnets of the "breakaway" to the "release" (4) insert the male usb from the "release" into the female port of the extension cable (5) insert the male end of the usb cable into the computers usb-a port. 


docs.buskill.in
buskill.in
*/

//acknowledgements to BaldGuyDIY for enclosure code

/*********** PARAMETERS ***********/

//magnet parameters 
magnet_position_x=3;
magnet_position_z=18.1;
magnet_position_y=4;
magnet_distance=20; //distance between magnets
magnet_size=3.175; // for 1/8" cube magnet
magnet_tolerance= .2; //to allow room for press fit

//r extrusion houses magnets on the release face
r_extrusion_x=4.75;//extrusion x
r_extrusion_y=1.75; //extrusion y
r_extrusion_z=8;//extrusion z


//USB male parameters 
u_h = 14; //height
u_w = 12; //width
u_d = 4.7; //depth 

//USB female parameters
u_f_h = 16; //height
u_f_w = 14.25; //width
u_f_d = 5.7; //depth 


//pogo parameters

pogo_length=7.6;
pogo_diameter=2.8; // pogo thickness
pogo_distance=1.5; //distance between pins 
shift=2.1; //distance from pins 
spread=4;
shift2=2; //distance from top

// pogo receptor parameters
size_difference = .7; // right now the code just uses pogo pin code scaled down by this variable

//jig slot variables

js_w=17.75;// 
js_h=8;
js_l=4.5;

//pogo house is the extrusion on the front of the breakaway face. the release face has a coresponding admission allowing for mating.
pogo_house_x = 15; //this is x
pogo_house_y = 1.25; // this is z
pogo_house_z =4; // this is y
pogo_house_pos_x= 31.75;
pogo_house_pos_y= 0;
pogo_house_pos_z= 2.25;

//pogo house 2 is the admission on the front of the release face. the breakaway has a corresponding extrusion allowing for mating

 pogo_house2_pos_x= pogo_house_pos_x+23.5;
 pogo_house2_pos_y= pogo_house_pos_y-r_extrusion_y-.25;
 pogo_house2_pos_z= pogo_house_pos_z;  

/*********** HARDWARE ***********/

//pogo pins

module pogos(){
    translate([-.3,.1,4.2]){
        
        translate([shift,0,0])
        rotate ([90,0,0])
        scale(.85)
        cylinder($fn = 30, $fa = 30, $fs = 2, h=pogo_length, r1=pogo_diameter/2, r2=pogo_diameter/2, center = true);
        
        translate([pogo_distance+spread,0,0])
        rotate ([90,0,0])
        scale(.85)
        cylinder($fn = 30, $fa = 30, $fs = 1.8, h=pogo_length, r1=pogo_diameter/2, r2=pogo_diameter/2, center = true);
            
        translate([pogo_distance+spread+spread-.5,0,0])
        rotate ([90,0,0])
        scale(.85)
        cylinder($fn = 30, $fa = 30, $fs = 2, h=pogo_length, r1=pogo_diameter/2, r2=pogo_diameter/2, center = true);
    
        translate([pogo_distance+spread*3-1,0,0])
        rotate ([90,0,0])
        scale(.85)
        cylinder($fn = 30, $fa = 30, $fs = 1.8, h=pogo_length, r1=pogo_diameter/2, r2=pogo_diameter/2, center = true);
}
}

//pogos();


// pogo receptors 

module pogo_recs(){
    translate([-.7,-.1,4.2]){
        translate([shift,0,0])rotate ([90,0,0])scale(size_difference)cylinder($fn = 30, $fa = 30, $fs = 2, h=pogo_length, r1=pogo_diameter/2, r2=pogo_diameter/2, center = true);
    translate([pogo_distance+spread,0,0])rotate ([90,0,0])scale(size_difference)cylinder($fn = 30, $fa = 30, $fs = 1.8, h=pogo_length, r1=pogo_diameter/2, r2=pogo_diameter/2, center = true);
            translate([pogo_distance+spread*2,0,0])rotate ([90,0,0])scale(size_difference)cylinder($fn = 30, $fa = 30, $fs = 2, h=pogo_length, r1=pogo_diameter/2, r2=pogo_diameter/2, center = true);
    translate([pogo_distance+spread*3,0,0])rotate ([90,0,0])scale(size_difference)cylinder($fn = 30, $fa = 30, $fs = 1.8, h=pogo_length, r1=pogo_diameter/2, r2=pogo_diameter/2, center = true);
}
}

//pogo_recs();

//usb male
module usb(){
    color("grey",.1)translate([-1,5,0])cube(size = [u_h,u_w,u_d],center=false);
}

//usb();

//usb female
module usb_p(){
    color("grey",.1)translate([-1,3.8,0])cube(size = [u_f_h,u_f_w,u_f_d],center=false);
}

//usb_p();


/** cube magnet **/
module magnet(){
color("grey") rotate ([90,0,0])translate([magnet_position_x,magnet_position_y,magnet_position_z])cube(magnet_size+magnet_tolerance, center=true);
    
   color("grey") rotate ([90,0,0])translate([magnet_position_x+magnet_distance,magnet_position_y,magnet_position_z])cube(magnet_size+magnet_tolerance,center=true);
    

}

//magnet();

/** disc magnet **/ 
module disc_magnet(){
color("grey") rotate ([90,0,0])translate([magnet_position_x,magnet_position_y,magnet_position_z])cylinder($fn = 30, $fa = 30, $fs = 2, h=4, r1=2.15+magnet_tolerance, r2=2.15+magnet_tolerance, center = true);
    
   color("grey") rotate ([90,0,0])translate([magnet_position_x+magnet_distance,magnet_position_y,magnet_position_z])cylinder($fn = 30, $fa = 30, $fs = 2, h=4, r1=2.15, r2=2.15, center = true);  

}

//disc_magnet();


// wire jigs

jig_w=17; //diff=2.5 to add room for slot
jig_h=2-.5;
jig_l=6.25;

slot_w=.75;
slot_h=jig_h/2;
slot_l=jig_l;

jigwall_w=slot_w;
jigwall_h=slot_h;
jigwall_l=jig_l-2;

var_w=1.25;
var_h=slot_h;
var_l=jig_l-2;

module var(){
    translate([spread+.4,0,var_h+.7])
    cube(size=[var_w,var_l,var_h], center=false);
    translate([spread+spread-.7+.5,0,var_h+.7])
    cube(size=[var_w,var_l,var_h], center=false);
     translate([spread+spread+spread-1.2+.5,0,var_h+.7])
    cube(size=[var_w,var_l,var_h], center=false);   
    
    }
 //   var();
    
    module var2(){
        translate([-25,0,0]){
    translate([spread-.1,0,var_h+.7])
    cube(size=[var_w,var_l,var_h], center=false);
    translate([spread+spread-.7,0,var_h+.7])
    cube(size=[var_w,var_l,var_h], center=false);
     translate([spread+spread+spread-1.2,0,var_h+.7])
    cube(size=[var_w,var_l,var_h], center=false);   
    
    }
}
//var2();

module slot(){translate([0,0,slot_h])cube(size=[slot_w,slot_l,slot_h], center=false);}
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

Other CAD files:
supplier/shenzen_qh_industrial_co/2021-05-24/una1.stl
Goldfishlaser Version/CAD Files/intermediary print files/pogo_pin.stl
digitalAssets/cad/cable/AS-BKA-CUP-001.FCStd
Goldfishlaser Version/CAD Files/intermediary print files/magnet.stl
Goldfishlaser Version/CAD Files/intermediary design files/dengineering_v02.scad
Goldfishlaser Version/CAD Files/intermediary design files/breakaway_v03.9.1.stl
Goldfishlaser Version/CAD Files/intermediary design files/breakaway_v03.9.stl
Goldfishlaser Version/CAD Files/intermediary design files/cubeface_v03.9.stl
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

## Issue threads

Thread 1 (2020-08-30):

Order magnets

maltfield, 2020-08-30:
This issue will track the progress on ordering the magnets that will be tested in our first prototype for this USB-A magnetic breakaway.

Requirements:
1. The magnets composition and dimensions must be common-off-the-shelf. They should be easily available in both large and small order quantities from a large number of manufactures and distributors.
1. One face of the magnet must be exposed on the inner-side of both ends of the breakaway adapter. There should not be a layer of plastic or any other material between the magnets when connecting the adapter's ends.
1. The magnets should be in some geometric shape such that they can simply be "dropped" into a void in the 3d-printed shell without the magnets falling-out. This rules-out cylinder and block magnets. Initial searches suggest that a tapered or hexagonal magnet (commonly sold on alibaba for electric motors) would meet this and the above requirements.
1. All dimensions of the magnets should be in nice (reasonably round) metric numbers

maltfield, 2020-08-30:
@goldfishlaser Can you please search alibaba for a list of distributors selling magnets that meet the above requirements at MOQ < 5?

If there's less than 100 vendors, can you please make a spreadsheet listing the following for each vendor?
1. Name of Vendor
1. URL of relevant product page
1. MOQ
1. Price/magnet
1. Sizes available (if relevant)
1. Comments
1. Any other relevant fields

Please make this spreadsheet in libreoffice, add it to this repo, and update this ticket as you progress on this task.

Thank you!

goldfishlaser, 2020-09-03:
Vendors expect an engineering drawing to accompany orders for hexagonal magnets.

Added first engineering drawing: https://github.com/BusKill/usb-a-magnetic-breakaway/tree/master/Engineering%20Drawings

The included pdf has a drawing for a 4mm thick 2mm long hexagonal magnet.

goldfishlaser, 2020-09-28:
Magnet vendor sent me an update that they're running a little behind and the revised shipping date for the magnets is October 10.

Having now worked a little further on the design of the shell, I have been thinking over the decision to use hexagonal magnets versus pentagonal magnets.

The pentagonal magnet would have a flat even surface on one side which would make it more amenable to being placed while the print is in progress. The hexagonal magnet, because it raises up on both ends, means that the printer, though it doesn't extrude where the magnet void is, will possibly travel across the space as though there isn't anything solid there.

However, I believe you preferred the magnets to be removable anyway? Therefore, it may be that there is no issue with the shape because we wouldn't print above the magnet, and instead it is held in place when fastened shut. Furthermore, I am not sure with the pentagonal shape, if the magnets would all be polarized in the same direction? Whereas with the symmetrical design, the magnet can be placed such that the opposite sides are able to attract.

This is how I am currently approaching the issue, that the shell is split in half and that the magnet does not get inserted during the print.

maltfield, 2020-09-29:
Everything should be disassembleable without damaging the device for hardware integrity verification checks.

That mostly applies to the data bus (of which the magnets are distinct), but I also don't like the idea of having to add items during the print. Seems more complicated, prone to error, and a hindrance to scaling the process-up (both printing or injection molding).

maltfield, 2020-10-08:
Any update on this? Did you find a vendor and place an order?

If yes, please post the name & URL of the vendor used. As well as the price and number of days from order-to-door.

goldfishlaser, 2020-10-08:
Oh, my bad. Yeah, the magnets are on the way. I'll update the magnet vendor sheet with these details during my next working session.

goldfishlaser, 2020-10-11:
The magnets arrived earlier today. Sorry for my delay in updating the github- I will highly prioritize that tomorrow.

goldfishlaser, 2020-11-28:
Updated vendor sheet, magnets are now in hand therefore closing this out

Closed 2020-11-28.

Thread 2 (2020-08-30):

Design Shell in FreeCAD

maltfield, 2020-08-30:
This issue will track the progress of making the shell for the magnetic breakaway adapter that can be 3D-printed for encasing the electronics that makeup the adapter.

This may change as the prototype progresses, but I'm imagining that the shell should:

1. Be constructed of 4x distinct pieces. There will be both a top and a bottom piece for both the input (side with the female USB receptacle) and output (side with the male USB plug) ends of the adapter.
1. The top and bottom pieces should attach in such a way that they're easy to disassemble. This is critical for defending against hardware implants; hardware integrity verification must be trivial. They should probably be connected by 1-4 bolts. Use nut catchers for durable plastic/metal composites.
1. The input and output pieces will connect with magnets
1. The input and output pieces will use pogo pins to connect the bus
1. The design of the shell should be asymmetric, such that the pins cannot be connected with reverse polarity (USB-A is non-reversible).
1. The shell's design should be solid, with voids cut-out that perfectly fit the components (pogo pins, USB receptacle/plug, magnets, wires)
1. The design of the shell should be only wide and tall enough to accommodate the USB components (so 12mm x 4.5 mm) plus the minimum amount of plastic needed to encase it) such that, when the adapter's plug is connected to a laptop or USB hub, it does not block other USB ports. If our simple-to-build design requires additional space, it should be made in depth, not width or height.
1. That said, the length should be kept as small as is reasonable. Additional length of the adapter means additional leverage, which makes it more likely to false-positive.
1. All measurements should be done in metric

maltfield, 2020-08-30:
@goldfishlaser please begin designing this in FreeCAD, add the freecad files to this repo, and update this ticket with your progress.

The first deliverable is a the 4x pieces with the voids cut-out for the both USB components on the outside of both the input/output sides only. Per our conversation, hopefully this can be met by Oct 11th.

goldfishlaser, 2020-09-07:
This existing thing has several elements worth borrowing for the design: https://www.thingiverse.com/thing:1986046
I plan to build on this design to meet our requirements.

maltfield, 2020-09-07:
This image is a bit concerning

 * https://cdn.thingiverse.com/renders/ca/3a/a3/8f/c6/d570a968626800f7b05f0d54fe4b6221_preview_featured.jpg

Is there any way to make the height the same as a normal USB flash drive?

goldfishlaser, 2020-09-19:
Forgot to link commit c3ea772085e12a0706d6918b73d211638f65eb3e to this issue

goldfishlaser, 2020-09-25:
https://imgur.com/a/dLotlTf

While waiting for magnets to arrive have made some mock magnets with the 3D printer. With USB and pogo rig for scale

goldfishlaser, 2020-09-26:
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

Printed commit b06ae4c4defcabd044fe7f436f2883688c80093e sans channels just to see what would happen.

Slipped in one of the mock magnets, which was definitely too big, but the nozzle squished it down. Assume that even if it was the real magnet, there will need to be some offset needed, but will wait to tune this for when real magnets arrive.

Is dimensions provided, but seems a bit smaller than it needs to be, in my opinion.

Tried sideways orientation of magnet instead of vertical but second guessing it.

goldfishlaser, 2020-09-26:
the pieces are all there as soon as I wrap my mind around what order things need to be added and subtracted and what not with each other..... 1d2513ab10a1fc361fbbc4e67d9b952ba91bf99f
Then I can add the voids for the USB pieces. Actually, maybe I should have added those first! *lightbulb* Well... until next time.

goldfishlaser, 2020-10-02:
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
status at f4ee6d9fb754e0baf13baecb50d75c94a6c84e90

maltfield, 2020-10-03:
Glad to see the progress! What's the height of it now in the above screenshot? Back to ~6.5mm?

goldfishlaser, 2020-10-03:
the left is 6.5 and the right is 8.5 but I realized I can trim it back down again to 6.5 and plan to do that.

goldfishlaser, 2020-10-04:
No, the female usb needs more room and I can't get 6.5 to work. I'm not even sure if 8.5 will work, but I'm making it 8.5 again. Will show pictures. I think we have the 2mm clearance.

goldfishlaser, 2020-10-04:
For commit b1841342dd6b7da82e78fef9e2f6d120d5c824a8
See October 3 https://imgur.com/a/dLotlTf

maltfield, 2020-10-04:
I can't view that image :( Did you mark the album public on imgur after uploading? Or is it just my browser being weird?

goldfishlaser, 2020-10-07:
So in our initial design discussion, you didn't mention requiring female pogo-pins AKA pp needles or pp contacts. I'm curious whether you think these are necessary, or whether you have any thoughts on what materials should be used.

maltfield, 2020-10-08:
Sorry, I'm ignorant about pogo pins. I'd assumed when you bought a pogo pin, it would ship with both ends. Maybe not.

> It may be that just solder is sufficient?

Please don't do this. I don't think it will be very durable for a connection that is going to be physically hit by a spring-loaded moving part over-and-over. I imagine it also would require skilled labour to build properly, increasing the barrier to build for n00bs--which we want to avoid.

I imagine it could be done with just a screw or something conductive, but I do think it would be best to use some cots/standard size pogo pin receptor/contact/female -nd on the other half of the adapter for best contact.

goldfishlaser, 2020-10-08:
Yeah, no I guess for a lot of applications, both ends aren't needed. So it seems almost always you have to get them separately.

It's hard to find vendors that will provide less than 500 units. But I'll do a more rigorous search.

goldfishlaser, 2020-10-11:
So I did some research on the pogo female connectors.

I can't really establish a "standard size" for this. My initial recommendation is this one:

https://www.alibaba.com/product-detail/3-7-mm-Height-SMT-Female_62394468419.html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

It has an MoQ of 500 but it's hard to get an acceptable size at a lesser MoQ.

You'll probably see the 2mm in the relateds- at 1000 MoQ. It works out to only 10 bucks more, though, so. I don't know, what do you think?

https://www.alibaba.com/product-detail/2-0-mm-Height-SMT-Female_62492338184.html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

I do like that it seems to have an additional groove in there that might help keep it in place.

maltfield, 2020-10-15:
Wow, that's a dumber/simpler designed piece of metal than I realized. A couple questions:
1. Are there lower MOQs available on AliExpress?
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
leoheck, 2023-05-03:
Oh nevermind, it is not possible to loopback the usb connector by just connecting d+ to d-, unfortunatelly.

leoheck, 2023-05-03:
Ah, another idea for you. Have you tried to bury the magnets in the middle of the print?
You start printing... then when the pocket is at its max height, you stop the print, insert the magnets and then restart the printing job. And you can make it to print 1 or 2 layers on top of it. It may work. It will be better than the glue and it will be hidden inside.

leoheck, 2023-05-03:
Alright, for magnets that are really strong, having a gap of 0.2 mm is too big (I was also using 0.28 mm for the layer height) the magnets jump out easily. Changing the gap to 0.1 mm (and printing the layer height at 0.2 mm) is perfect.

Having a male/female mating design with a 1 mm tab around is a very satisfying fit. But then we lose the ability to disconnect it by moving it perpendicularly to the axis that attaches the USB to the computer.

Here is a quick test.
The one with tape has 0.2 mm gaps around and the same in depth.
The one without it has 0.1 mm gaps around and 0.2 mm in depth.
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

here is the satisfying sound.
https://user-images.githubusercontent.com/1277920/236074509-921c56b4-cb63-4fad-bdc1-c90837ef7fd2.mp4

goldfishlaser, 2023-05-04:
> Ah, another idea for you. Have you tried to bury the magnets in the middle of the print? You start printing... then when the pocket is at its max height, you stop the print, insert the magnets and then restart the printing job. And you can make it to print 1 or 2 layers on top of it. It may work. It will be better than the glue and it will be hidden inside.

I haven't gotten a workflow for creating files with automatic pausing because I currently only use Flashprint software with my 3D printer. It's on my to-do to learn how to do that, but for now it isn't really easy for me to make a design based on pausing the print. However, I think a design that incorporates that feature would be great.

goldfishlaser, 2023-05-04:
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

Please forgive me if I misunderstand your questions:

1. The cable is because we want to create a connection from the USB port to the body. The idea is that if someone separate the laptop from the body (either by cutting the cord or because the magnetic release separates), BusKill software triggers.
2. Yes, BusKill is triggered if you remove any USB device (while BusKill is armed) that is connected directly to the computer, regardless of whether it has a cord.
3. I do not have enough EE skill to know the answer to this question. However, on the wishlist for BusKill is "A simple-as-possible open-source USB peripheral that can send [USB hotplug events](http://libusb.sourceforge.net/api-1.0/group__libusb__hotplug.html#ga00e0c69ddf1fb1b6774dc918192e8dc7) but doesn’t have the ability to send data to the machine, including a low-tech guide to [verify the integrity](https://www.bunniestudios.com/blog/?p=5706) of the device."

leoheck, 2023-05-04:
You got all my questions right.

1. So, the device has to be physically attached to the body of the user. Got it. Then a rope/strap attached to one of the parts wouldn't be enough? It can be attached to the usbdrive actually, right?

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

> Ps. Sorry did not have a napkin around here.

3. Actually, it is not as simple as that, so extra logic would be necessary to attach the d+ to the d-. I was just thinking about the tx/rx on a serial device. I am going to forget about this for now since any extra logic could increase the length of this thing.

leoheck, 2023-05-04:
Alright, the magnets I have are good.
My test was really promising, at least for my standards haha.

I got a USB male connector from a broken cable.
I also have a USB-female connector from a broken USB-C to a USB-A adapter.

I think I have pogo pins too. They may be a bit smaller than what is needed or even possible to use, but I will try to use them.  I am thinking that I could group 3 or 4, to make a thicker version. Let's see, first I have to find them.

So, having everything I can maybe my own version of this. I would like to use the spring-loaded pogo ping set with magnets, but this is a far dream for me. It takes time to get these things and I like to be quick. I am going to keep this for the second version if the first works fine.

> BTW, your print looks awesome and thanks for the details about your print settings. For the record, I've been using .20 layer height.

Ah, no problem, it is a fun project and now I realized that I can actually build a working thing. And that is even nicer.

goldfishlaser, 2023-05-04:
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

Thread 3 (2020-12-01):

Hole for connector to wrist strap

PowerPress, 2020-12-01:
It would be nice if there were decent sized hole so you could have a connector in the hole and a wrist strap attached to the connector around your wrist. So it would be easy to jerk your wrist away if you wanted to trigger the device without having to reach  for it. Essentially the laptop would be leashed to the user if the user desired in case a thief just grabbed it and tried running it would require no involvement on the user to enable the protection mechanism.

https://www.bhphotovideo.com/c/product/601276-REG/Olympus_202316_Adjustable_Wrist_Strap_Water.html/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

maltfield, 2020-12-01:
BusKill is already designed to connect to the body at the hip. I think the only thing a wrist connection would change is increase the false-positive rate.

 * https://docs.buskill.in/buskill-app/en/stable/introduction/quickstart.html

Closed 2021-05-18.

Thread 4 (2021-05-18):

Supplier Research (no 3D printing)

maltfield, 2021-05-18:
This issue will track my attempts to find a supplier to manufacturer the USB-A Magnetic Breakaway component.

This will happen in parallel as we continue with efforts on the ideal solution, which is a totally open-source, 3D-printable shell that can be built easily, low-tech, with COTS components.

 * https://github.com/BusKill/usb-a-magnetic-breakaway/issues/2

But we can't let perfect be the enemy of the good, and as I write this there's many non-techie journalists, sources, activists, etc that could benefit from having a pre-assembled BusKill cable available for purchase. To fast-track that end-goal, I'll try to find a supplier who can make this component for us -- or supply us with the components sufficient for us to make it ourselves with non-trivial manufacturing required on our end.

maltfield, 2021-05-18:
I've only ever found one supplier of a USB-A magnetic breakway: Griffin Technology. This is what I used to build my original BusKill cable, and--well--they totally sold-out on Amazon after I linked-to them in my original article describing how to build a BusKill cable:

 * https://tech.michaelaltfield.net/2020/01/02/buskill-laptop-kill-cord-dead-man-switch/

3 weeks ago I contacted Griffin's Sales Manager for Retail & Distribution in Europe (triccardi _at_ incipio.com), and he informed me that they EOL'd their magnetic breakaway adapters--both in USB-C and USB-A. I asked what would be required to jumpstart production, but I got no response.

maltfield, 2021-05-18:
I tried last week to signup for an alibaba account, but I kept getting this error

```
The mobile number or email address is blacklisted
```

It wasn't at all clear if the issue was my email address or phone number. I tried several. Eventually I got it to work with an old gmail account that I fortunately still have access to.

After I logged-in I tried to change to my real email address again, but it wouldn't work. I opened a support chat and quickly was told that they ban any email addresses with `alibaba` in their name. Well, that breaks my email address naming convention, but I found that using `babaali` worked fine :shrug:

maltfield, 2021-05-18:
I found several vendors of interest. For this first round, I decided to contact three vendors that all manufacture exactly what we need, but with USB-C.

 1. Shenzhen Bvanki Technology Co., Ltd.  https://www.alibaba.com/product-detail/2020-Non-magnetic-to-Magnetic-Adapter_62510448064.html

 1. Shenzhen EONLINE Industrial Co., Ltd. https://www.alibaba.com/product-detail/Eonline-3A-Type-C-Adapter-Magnetic_1600096650403.html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

 1. Sichuan Mandick Import And Export Trade Co., Ltd. https://mandick.en.alibaba.com/?spm=a2700.wholesale.cordpanyb.2.92f23cf8bBQCTf

```
Hi,

Is it possible for you to make a Magnetic Breakaway for USB type A (standard USB)?

 * <link to their product>

The item above is similar to what I'd need, except I want the male end to be a USB-A male end and the female end to be a USB-A female end.

Please let me know if you have this item available in USB type-A (standard USB, not USB-C) only.

Thank you,
Michael
```

maltfield, 2021-05-19:
All 3x suppliers said they don't make usb magnetic breakaways for USB-A.

I followed-up with a request to make a customized order, but I think these vendors all specialize in accessories for mobile phones, which is the market for these USB-C adapters and they don't do USB-A.

maltfield, 2021-05-19:
I messaged another 8 vendors, all appeared from the first page when searching for "usb pogo pin magnetic pdb" on alibaba

1. Shenzhen QH Industrial Co., Ltd. https://mold-parts.en.alibaba.com/product/1600237806652-826886905/Professional_Magnetic_USB_A_to_micro_USA_Cable_Connector_Male_Female_Pogo_Pin_Connector.html
2. Shenzhen Like Hardware Electronics Co., Ltd. https://shenzhenlk.en.alibaba.com/product/62074920029-811716276/4_Pin_Magnetic_Connector_4_Pin_Pogo_Pin_To_Usb_Cable_PCB_4Pin_Connector_Male_Female_Connector_Smartwa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
2. Hyte Technology Limited https://hytepro.en.alibaba.com/product/62327772156-812944918/4_pogo_pin_data_magnetic_pcb_connector_with_female_and_male.html
3. Hytepro Technologies Limited https://hyte.en.alibaba.com/product/1600089874345-805606376/Hytepro_positive_4pin_magnetic_charger_cable_connector_dc_pcb_adapter.html
4. Shenzhen QH Industrial Co., Ltd. https://mold-parts.en.alibaba.com/product/1600214253589-812290259/High_Quality_Pcb_Pogo_Pin_Usb_Male_Dc_4_pin_Magnetic_Charging_Cable_Automotive_Electrical_Connector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
5. Dongguan Bofan Technology Co., Ltd. https://dgbofan.en.alibaba.com/product/60825989769-0/4_Pogo_Pin_Magnetic_Usb_Waterproof_3_0_Port_Connector_Micro_Usb_Waterproof.html
6. Dongguan Cfe Electronic Co., Ltd. https://cfconn.en.alibaba.com/product/60783675303-804434158/White_4pin_Magnetic_Pogo_Pin_Connector_Adapter_4p.html
7. Dongguan Access Star Electronic Co., Ltd. https://access-star.en.alibaba.com/product/60677449119-812371672/Braided_Magnet_Android_Magnetic_Charging_USB_Cable_POGO_cable.html

maltfield, 2021-05-22:
One of the vendors above (Una Ou from Shenzhen QH Industrial Co., Ltd) understood my inquery and provided a couple images of a possible solution. It's not an adapter like the prototype, but I think this cable will meet our requirements

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

maltfield, 2021-05-25:
Shenzhen QH Industrial Co., Ltd sent their catalog.

 * https://github.com/BusKill/usb-a-magnetic-breakaway/blob/master/supplier/shenzen_qh_industrial_co/productCatalogue_2020_rev5.pdf

And a `.stl` file for our customized cable as requested.

 * https://raw.githubusercontent.com/BusKill/usb-a-magnetic-breakaway/master/supplier/shenzen_qh_industrial_co/2021-05-24/una1.stl

I responded saying that the cable looks OK but the length is way off. And asking what the MOQ would be.

maltfield, 2021-05-26:
QH fixed the .stl file's cable length and also the double-male-end so it's actually a proper extension cable. Updated .stl is here:

 * https://github.com/BusKill/usb-a-magnetic-breakaway/blob/master/supplier/shenzen_qh_industrial_co/2021-05-26/4Pin_2.54mmPH_runway_male_female_magnetic_connector_with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

Raster gimp .xcf files are here:
 * https://github.com/BusKill/usb-a-magnetic-breakaway/tree/master/digitalAssets/logo/2020_raster

maltfield, 2021-05-26:
Per our conversation @goldfishlaser will try to convert the logo to an svg with inkscape and then teach me how to engrave it onto the overmold in the .stl using freecad.

maltfield, 2021-06-03:
I was finally able to pocket the logo into the cable overmold!!

This commit has the freecad file with buskill logo "carved" into the overmold of the custom adapter housing the USB-A female receptacle.

I think the reason freecad kept figthing me was because of the way it handles imported .stp files or something. Anyway, I discovered the following process permitted me to pocket the logo into the overmold:

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

  1. Import the logo in svg format

  2. Convert the logo from a draft to a sketch (Draft Workbench -> Convert bidirectionally between draft & sketch objectt) -- Do *not* combine all of the individual letters into one sketch, else you'll be unable to pocket it because the sketch's bodies are dijointed

  3. Create a new body at the root of the freecad file *outside* the .stp tree (yellow staircase/step icon)

  4. Click & drag the overmold to this new body

  5. Click & drag all the sketches of the logo's letters into the same body as the overmold

  6. Ctrl+click to slect all of the logo's letters. Click the "Data" tab, expand the "Position" field, and click +/- on the axis until the logo is position above the overmold (it doesn't matter how close it is, just fiddle with the two coordinates so the letters are centered atop the overmold.

  7. Double-click the body to activate it.

  8. One-by-one, click the sketches and choose Part Design -> Pocket. Figure out the right mm so it just carves into the surface without going through it. Do this again for each letter.

maltfield, 2021-06-10:
I asked Shenzhen QH Industrial Co., Ltd if the size of the female connector was reasonable. She contacted the tools team and came back with this. It's larger, and seems much more practical

<p align="center">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</p>
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
maltfield, 2021-06-21:
Of the list of alibaba vendors on the previous post, there are some providing a male-female USB-C magnetic breakaway adapter that wouldn't require a Frankenstein conglomeration including the female-female adapter.

1. https://eonline.en.alibaba.com/company_profile.html

maltfield, 2021-06-22:
Yesterday I contacted the above 3x vendors on alibaba. The last two seem like small-time players, but the first one sent me a whole catalog page of their various USB magnetic adapters

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

maltfield, 2021-06-28:
I'm still struggling to get the payment link from EONLINE.

Meanwhile, I should probably find the USB-C (male) to USB-A (female) 1m "extension cable" whoose male-end would plug into the above USB-C magnetic breakaway adapter and whose female receptacle would take-in the USB-A thumb drive.

I searched for options of 1m cables, and I found only a couple. I think it makes more sense to search for all the vendors that sell the cables and just ask if they can make it in 1m lengths. For this, I searched for "usb otg cable" and selected the "USB Type: TYPE-C" option and only "Seller Type: Assessed Supplier" and "Product Type: Ready to Ship". I sorted & `uniq`d the results, and here's the complete list:

1. https://4successful.en.alibaba.com/company_profile.html
1. https://7west.en.alibaba.com/company_profile.html
1. https://cantell.en.alibaba.com/company_profile.html
1. https://cnbloom.en.alibaba.com/company_profile.html
1. https://cnmagelei.en.alibaba.com/company_profile.html
1. https://cnwistar.en.alibaba.com/company_profile.html
1. https://dashengvytech.en.alibaba.com/company_profile.html
1. https://dgbofan.en.alibaba.com/company_profile.html
1. https://dgxunguang.en.alibaba.com/company_profile.html
1. https://doonjiey.en.alibaba.com/company_profile.html
1. https://eonline.en.alibaba.com/company_profile.html
1. https://googfit.en.alibaba.com/company_profile.html
1. https://guobuy.en.alibaba.com/company_profile.html
1. https://gzkallin.en.alibaba.com/company_profile.html
1. https://haiyijin.en.alibaba.com/company_profile.html
1. https://logee.en.alibaba.com/company_profile.html
1. https://magelei.en.alibaba.com/company_profile.html
1. https://opelu.en.alibaba.com/company_profile.html
1. https://oudakx.en.alibaba.com/company_profile.html
1. https://pogocharger.en.alibaba.com/company_profile.html
1. https://sanguanideatech.en.alibaba.com/company_profile.html
1. https://sbtool.en.alibaba.com/company_profile.html
1. https://suntc.en.alibaba.com/company_profile.html
1. https://szbst.en.alibaba.com/company_profile.html

maltfield, 2021-06-29:
The following suppliers said they could make a USB-C male -> USB-A female OTG cable in 1 meter lengths:

| Vendor | MOQ | Price/Ea |
--- | --- | ---
|Shenzhen Sanguan Siyuan Technology Co., Ltd.| 300 | 1.58 |
| Shenzhen Sunning Tension Industrial Co., Ltd. | ? | 0.84USD |

maltfield, 2021-11-14:
Shenzhen QH Industrial Co informed me that the first-sample-run of the custom BusKill magnetic breakaways had some atheistic defects, and they "still need to improve the mold for good tolerance and aesthestic quality."

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

maltfield, 2022-07-29:
We were able to find all the suppliers we need and are now selling the manufactured injection-mold USB-A BusKill cables directly on our website and through Crowd Supply

 * https://buskill.in/buy

goldfishlaser, 2023-05-05:
photos attached:

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

goldfishlaser, 2023-05-06:
Additional photos

Cord

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
No shielding nor drain wire.

Other connectors insides
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

Closed 2022-07-29.

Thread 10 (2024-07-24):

Detect Malicious STL files

maltfield, 2024-07-24:
This issue will track the effort to implement some mechanism to scan (or sanitize) `.stl` files committed in PRs

maltfield, 2024-07-24:
Here's an example real-world file change (taken from the PR mentioned in the OP)

```
wget -O pre.stl https://raw.githubusercontent.com/BusKill/usb-a-magnetic-breakaway/master/Goldfishlaser%20Version/CAD%20Files/intermediary%20design%20files/usbamagb_v04.0.stl
wget -O post.stl https://raw.githubusercontent.com/goldfishlaser/usb-a-magnetic-breakaway/ee7b7862f07bda4b132e177e7807fb50050db464/Goldfishlaser%20Version/CAD%20Files/intermediary%20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

diff pre.stl post.stl
```

The good news is that the `.stl` file is just a plaintext file, but the bad news is that the diff is >100,000 lines long

```
user@disp2114:~$ diff pre.stl post.stl | wc -l
106982
user@disp2114:~$
```

maltfield, 2024-07-24:
I created [this question on SE](https://security.stackexchange.com/questions/277974/how-to-scan-and-sanitize-stl-files) to see if there's already a tool available to scan or sanitize `.stl` files

 * https://security.stackexchange.com/questions/277974/how-to-scan-and-sanitize-stl-files

maltfield, 2024-07-25:
I opened a feature request for Dangerzone to support `.stl` files:

 * https://github.com/freedomofpress/dangerzone/issues/876

maltfield, 2024-07-25:
I read the [TALOS-2022-1594](https://talosintelligence.com/vulnerability_reports/TALOS-2022-1594) report published in April 2023 that describes the heap buffer overflow vulnerability in ADMesh v0.98.4 due to a maliciously-crafted `.stl` file, but unfortunately they didn't publish an example of the `.stl` file.

I'm curious if this issue can only be caused by binary files, so maybe it's sufficiently mitigated by only accepting plaintext `.stl` files?

Or maybe the maliciously-crafted `.stl` file doesn't comply with the STL syntax, such that we can greatly reduce our risk by simply doing a syntax check on a plaintext `.stl` file (refusing to merge if there's errors)?

I asked Talso and the ADMesh dev to please publish the maliciously-crafted `.stl` file, so that we could study it

 * https://github.com/admesh/admesh/issues/60#issuecomment-2251209542

maltfield, 2024-07-25:
See also:

 * https://graphicdesign.stackexchange.com/questions/165755/verify-syntax-of-stl-file

maltfield, 2024-07-28:
See also [Export STL file (in plaintext) in FreeCAD](https://forum.freecad.org/viewtopic.php?p=773391#p773391)

 * https://forum.freecad.org/viewtopic.php?p=773391#p773391

maltfield, 2024-07-28:
See also [Writing an .stl file from scratch](https://danbscott.ghost.io/writing-an-stl-file-from-scratch/)

 * https://danbscott.ghost.io/writing-an-stl-file-from-scratch/

goldfishlaser, 2024-08-29:
See https://doi.org/10.1145/3471621.3471843

maltfield, 2024-08-29:
Interesting. Quick review of the linked file above describes methods of using `.stl` files as a means to in/exfiltrate data with (encrypted) steganographic data encoded *inside* of objects. They describe use-cases of "watermarking" 3D IP. Blech.

Anyway, the relevant bit that I see is their `Three Contexts of Distinguishability` section, where they talk about how to sanitize STL files.

>  each and any of these can determine a defender’s ability to detect the subliminal steganographic channel and even extract the encoded message for further analysis. Such detection is critical for follow-on security procedure...
> With the proposed bit encoding scheme, the “sanitization” of STL
files is fairly simple and straightforward. Defenders can overwrite
all facets in the file with either the same value (0 or 1) or with a
completely random value. As mentioned before, due to the semantic
equivalency of the vertex cyclical rotation, it should not affect
the described 3D object geometry. However, while theoretically
sound, this assumption needs to be verified empirically; we plan to
conduct such an investigation in a follow-up work. Consequently,
the proposed approach is fragile, and can be easily disrupted by the
described sanitation approach.

maltfield, 2024-08-29:
@goldfishlaser I think a STL sanitizer would make a great tool to present at DEF CON :P

goldfishlaser, 2024-08-29:
I don't disagree. Their paper was pretty entertaining.

goldfishlaser, 2024-08-29:
I plan to get my next free ticket by becoming a goon though :P

goldfishlaser, 2024-08-29:
I still don't think banning/fearing STLs is the move though.

On Thu, Aug 29, 2024, 18:25 Michael Altfield ***@***.***>
wrote:

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

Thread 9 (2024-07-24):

Detect Malicious Unicode in PRs

maltfield, 2024-07-24:
This issue will track the effort to implement some mechanism to scan commits in PRs for malicious unicode (eg bidi or homoglyph characters)

For more info, see [Trojan Source](https://www.trojansource.codes/trojan-source.pdf)

 * https://www.trojansource.codes/trojan-source.pdf

maltfield, 2024-07-24:
I added a CI workflow to detect unicode characters to PRs in this repo, as described here:

 * https://tech.michaelaltfield.net/2021/11/22/bidi-unicode-github-defense/

New PRs should get a comment from the bot indicating if unicode characters are detected (or not).

Closed 2024-07-24.

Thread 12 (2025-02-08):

USB-C Injected Molded Variant

maltfield, 2025-02-08:
This ticket will track the effort to make a version of the BusKill cable with a USB-C plug.

# Why?

At the time of writing, the only BusKill cable that we sell has a USB-A plug. Currently, if a user has a laptop with only USB Type-C ports, we recommend that they:

1. [Make their own](https://docs.buskill.in/buskill-app/en/stable/hardware_dev/bom.html#usb-c-variant) cable
2. Use an [adapter](https://docs.buskill.in/buskill-app/en/stable/hardware_dev/bom.html#usb-c-hybrid)

Recently we had an uptick of requests for a "native" USB-C BusKill cable, including for Henry Fisher in his [review of the BusKill on TechLore](https://neat.tube/w/sRkFue3cH924j6Q1nuUAZG).

Thanks to good sales of the USB-A BusKill cable, [ASI](https://www.altshift.in/) has decided to research into the possibility to provide this option.

# How?

Previously [I had thought](https://github.com/BusKill/usb-a-magnetic-breakaway/issues/4) that a USB-C version would be an entirely different cable.

I had looked at [these USB-C charging cables](https://github.com/BusKill/usb-a-magnetic-breakaway/issues/4#issuecomment-866247981), typically sold with magnetically-detachable tips for compatibility with different devices/busses. The problem with this is that the quality of many of these are terrible, the suppliers come-and-go too frequently, and most of them are male on both ends.

Today I'm finishing-up our third production run of the injection-molded USB-A cables (which we've been selling since 2022), and it occurred to me that we actually might be able to just use our existing USB-A magnetic coupler/receptacle for the USB-A storage drive with a new cable that has a USB-C plug on it instead of a USB-A plug.

maltfield, 2025-02-08:
Arguably this ticket should be located in a new repo. Or I should rename this repo 'hardware'.

But:
1. renaming repos breaks things,
2. I don't really want to complicate things by having a second repo, and
3. well, this end result is for a device that has USB-C male on one side and USB-A female on the other, so it's still technically within the scope of a 'usb-a-magnetic-breakaway', right?

goldfishlaser, 2025-02-08:
3 is the most convincing argument. And we so far have it set up so that
variations get their own directory.

I do support the idea of this repo supporting any type of hardware design
though, and while changing names breaks things perhaps worth it to do
sooner rather than later?

On Sat, Feb 8, 2025, 12:31 Michael Altfield ***@***.***>
wrote:

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

maltfield, 2025-02-08:
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

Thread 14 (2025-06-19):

USB A key loop source?

techrivertree, 2025-06-19:
When I first heard about buskill, I was in a hurry (moving in a week) so I about the $60 version.

I like DIY projects but I cannot find a short USB A key loop thing to connect a d ring to. What are all of you using? Link(s) would be helpful.

goldfishlaser, 2025-06-20:
> When I first heard about buskill, I was in a hurry (moving in a week) so I about the $60 version.
>
> I like DIY projects but I cannot find a short USB A key loop thing to connect a d ring to. What are all of you using? Link(s) would be helpful.

I hope I'm understanding correctly, but I believe I take a different approach and use USBs that include a keyhole already. I can create a list of ones I've found that work nicely next time I get a chance. I'm going to be doing a livestream soon and plan to talk a little more at that time about considerations in selecting usb drives as well.

maltfield, 2025-07-22:
Just any USB drive with a hole and a keyring should work. Relevant links:

 * https://docs.buskill.in/buskill-app/en/stable/hardware_dev/bom.html
 * https://www.buskill.in/buskill-laptop-kill-cord-dead-man-switch/

Closed 2025-07-22.

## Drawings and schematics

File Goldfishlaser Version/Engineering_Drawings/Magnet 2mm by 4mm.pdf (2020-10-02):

N

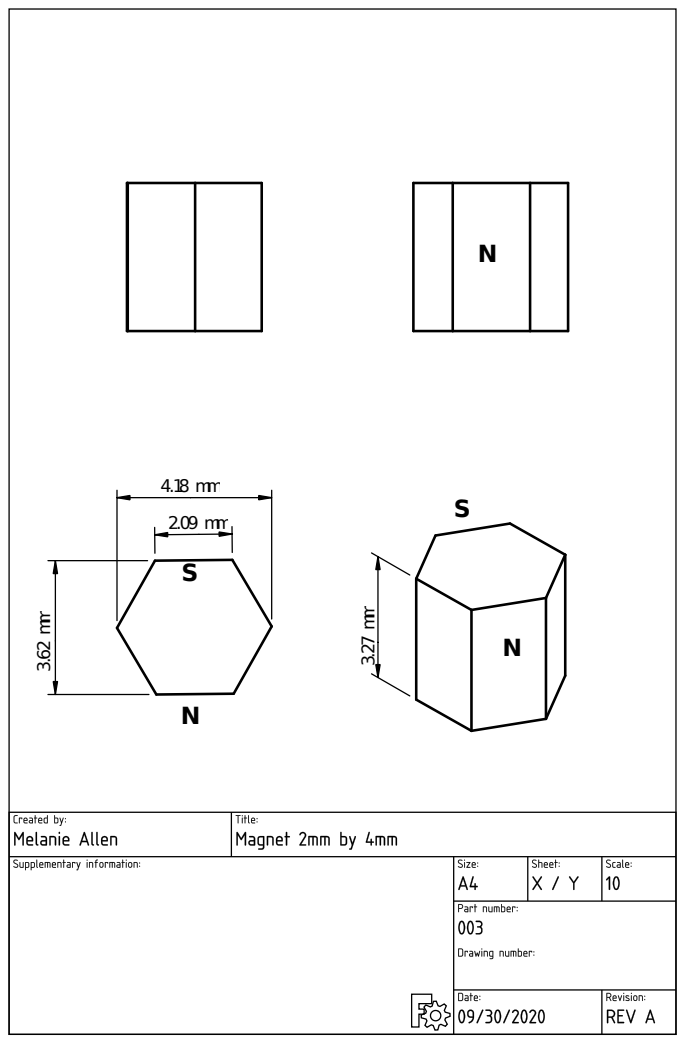
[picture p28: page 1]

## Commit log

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2020-09-08 Part of issue#1 -- add engineering drawings which were submitted and which the order is now active. Empty Calc doc added which will contain list of vendors.
    [Magnet_Vendor_List.ods, Shell_Assembly.FCStd]
2020-09-09 issue #1 added vendors to spreadsheet
    [Magnet_Vendor_List.ods]
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2020-09-19 beginning work drafting shell -- looks like madness right now but this is the progress so far
    [Shell_Assembly.FCStd, magnet.stl, magnet2.stl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]
2020-09-26 fixed magnet position, fixed pogopin channels. however, pogopin channels aren't rendering, despite not throwing an error. Not sure what is going on. The next steps are to take the intersection of the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
    [Magnet_2mm_4mm.fcstd, magnetic_release.scad, pogo_pin.scad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]
2020-09-26 Directly adding in the scad file instead of using the STL helps render it, but now I got to figure out how to code this. Bit of a challenging problem to keep the voids I want and the solids I want. B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
    [magnetic_release.scad, magnetic_release.stl, pogo_pin.stl]
2020-09-26 cleaned up my code and added more comments, temporarily removed pogo pin and replaced with usb voids
    [magnet.stl, magnet2.stl, magnetic_release.stl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]
2020-10-02 updated drawing with polarities. made pogo voids from scratch in hope of easier modeling.
    [magnet2.stl, magnetic_release.scad, magnetic_release3.stl]
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2020-10-04 corrected license in my code, I must have accidentally copied the wrong one
    [magnetic_release.scad]
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2020-11-28 rename and edit vendor list, update magnet order, add pp tab with pp info
    [Magnet_Vendor_List.ods, Magnet_and_PP_Vendor_List.ods]
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2020-11-28 correction to screw sizes
2020-11-28 making edits to a new file just in case I need to revert. added holes for screws to female case. Need to rework some things so that I can increase the pogo pin hole dimensions. issue#1
    [magnetic_release_new.scad]
2021-03-02 cleaned up tabs while reviewing code, moved old CAD files into an archive folder, updated vendor list with pogo pin receptor receipt information issue#2
    [Magnet_and_PP_Vendor_List.ods, magnetic_release.scad, magnetic_release_experiment.scad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]
2021-03-02 adding more comments to code, makinng progress towards resolving "not valid manifold error". issue#2
    [magnetic_release_new.scad]
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2021-03-02 creating nut catchers issue#2
    [magnetic_release_new.scad]
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2021-03-06 broke stuff to remake better, continuing to rearrange and comment code to improve readability, changed variable names for readability, adding color and other cues as well.
    [magnetic_release_new.scad]
2021-03-07 issue#2 making progress rebuilding breakwaway base
    [magnetic_release_new.scad]
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2021-04-10 worked on breakaway lid. a few more tweaks needed to breakaway lid before ready to print issue#2
    [magnetic_release_new.scad]
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2021-04-10 fiddling with distances, minimizing size, preparing to add nut and screw holes back to release then splitting into the three parts.
    [magnetic_release_new.scad]
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2021-05-22 printed test, fixing sizes
    [magnetic_release_522_no_m.stl, magnetic_release_new.scad]
2021-05-25 Added files for "supplier" research.
    See https://github.com/BusKill/usb-a-magnetic-breakaway/issues/4
    [una1.stl]
2021-05-26 adding updated .stl and also gimpt digital assets (for conversion to svg & adding to .stl engraving)
    [4Pin_2.54mmPH_runway_male_female_magnetic_connector_with_USB-Female_adapter.stp]
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2021-05-26 minor correction
    [magnetic_release_new.scad]
2021-05-28 try a test print see where we're at, engraved buskill in there for fun
    [magnetic_release_527_no_m.stl, magnetic_release_new.scad]
2021-05-31 added logo to freecad file, extruded to 10mm. TODO: pocket it from overmold
    [buskill_usba_magnetic_breakaway_cable.FCStd]
2021-06-01 adding a new freecad file with sketch on the right face.
    not sure how to remove the disassociated bodies extruded from the
    imported svg logo from the previous attempt. Now I've mapped the sketch
    on the face of the overmold, but I'm not sure how to move the sketch. I
    get this weird wirefame of green spiraly lines that cover-up everything
    on the screen when I attempt to edit the sketch..
    [buskill_usba_magnetic_breakaway_cable_2.FCStd]
2021-06-02 next attempt at getting the logo pocketed from the overmold
    This time I learned how to use the draft tool to rotate & move a sketch,
    then I also made the individual sketches into distinct bodies in a
    group. And I dropped their location on the y axis to sit just on-top of
    the overmold.
    Next I just need to figure out how to pad them and then subtrack them
    from the overmold, which seems non-trivial because the imported overmod
    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
    [buskill_usba_magnetic_breakaway_cable_2.FCStd, buskill_usba_magnetic_breakaway_cable_4.FCStd, buskill_usba_magnetic_breakaway_cable_4a.FCStd]
2021-06-03 I was finally able to pocket the logo into the cable overmold!!
    This commit has the freecad file with buskill logo "carved" into the overmold of the custom adapter housing the USB-A female receptacle.
    I think the reason freecad kept figthing me was because of the way it handles imported .stp files or something. Anyway, I discovered the following process permitted me to pocket the logo into the ove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
    1. Import the logo in svg format
    2. Convert the logo from a draft to a sketch (Draft Workbench -> Convert bidirectionally between draft & sketch objectt) -- Do *not* combine all of the individual letters into one sketch, else you'll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
    [buskill_usba_magnetic_breakaway_cable_4d.FCStd]
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2021-06-22 added eonline catalog & links to other USB-C magnetic adapter suppliers on alibaba.
    See also https://github.com/BusKill/usb-a-magnetic-breakaway/issues/4
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2021-12-17 adding the first sample we recieved. the pinout sends power but not data :( other than not working, it looks most great except the sides of the overmold are a little rough
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2022-01-18 update to mangetic_release_new.scad is a minor edit to clarify that now the device is meant to print in 3 pieces instead of 2. Intermediary print files include version that could print the base and r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
    [justbreakaway_base.stl, justrelease.stl, magnetic_release_new.scad]
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2022-01-19 color coded, added release and breakaway midpiece block. some issues with how I nested modules. proceeded without refactoring which would probably make this file easier to use and understand.
    [magnetic_release_new.scad]
2022-01-19 did I see three? meant four... refactor definitely needed on next commit... otherwise will be unnecessarily difficult to carve the middle pieces.
    [magnetic_release_new.scad]
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2022-01-22 oops... fixed mistake
    [magnetic_release_new.scad]
2022-01-22 cut out usb void. dimensions of everything are in the air while trying to assign variables that establish uniformity
    [magnetic_release_new.scad]
2022-01-22 realized I left off with a wonky shape for the pogo receptors. gotta fix two_pogo_recs module next session, then can proceed to difference.
    [magnetic_release_new.scad]
2022-01-22 freed magnets and screw holes from nested modules. ready to difference next session.
    [magnetic_release_new.scad]
2022-02-03 fixed pogo receptors
    [magnetic_release_new.scad]
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2022-02-07 fixing some things, breaking other things, as you do.
    [magnetic_release_new.scad]
2022-02-07 fixing middle pieces
    [magnetic_release_new.scad]
2022-02-07 I really hate how I created the release and it plagues me. nevertheless, continuing to kludge things into place.
    [magnetic_release_new.scad]
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2022-02-08 just a few more revisions left before we're ready tosee what this prints.
    [magnetic_release_new.scad]
2022-02-11 moved breakaway midpiece code more proximate to all the other midpiece modules
    [magnetic_release_new.scad, moonbowl.scad]
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2022-12-17 sometimes it has to get worse before it gets better. right in the middle of the refactor.
    [magnetic_release_v0.8.scad]
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2023-02-02 Had to rewrite some stuff, right now the breakaway is only the void without the block. Next will refine the void, then cut it out of the block. Renamed some stuff and added some shenanigans to help m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
    [magnetic_release_v0.8.scad]
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2023-02-05 everything is almost where it needs to be. Next: minor change to mid pieces, then really start work on the details of the fastening voids
    [magnetic_release_v0.8.scad]
2023-02-05 Decided to remove the code for the screws entirely and tackle the issue differently
    [magnetic_release_v0.8.scad]
2023-02-05 fixed midpiece pogo recs
    [magnetic_release_v0.8.scad]
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2023-02-05 fixed errant comments
    [magnetic_release_v0.8.scad]
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2023-02-08 fixing dimensions
    [magnetic_release_v0.8.scad]
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2023-02-20 more minor fixes
    [magnetic_release_R_v09.stl, magnetic_release_v0.8.scad]
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2023-02-20 minor fixes
    [magnetic_release_R_v09.stl, magnetic_release_v0.8.scad]
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2023-02-24 added the two magnet voids to the breakaway. added position to the assembly module.
    [magnetic_release_v0.8.scad]
2023-02-24 continuing to dial in issue #2
    [magnetic_release_v0.8.scad]
2023-02-24 minor fix #2
    [magnetic_release_v0.8.scad]
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2023-04-23 Corrected comments
    [magnetic_release_v0.8.scad]
2023-04-29 started working on new design which is going to have bigger wire channels and +1 wire channel to accomodate shielding wire.
    [magnetic_release_v0.9.scad, magnetic_release_v0.9.stl]
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2023-05-04 issue#2 starting over
    [mag_startover.stl, magnetic_release_v0.9.stl]
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2023-05-13 needed more tolerance added to usb and pogo pins
    [dengineering_vesion.scad, dengineering_vesion.stl]
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2023-06-10 replaced oval magnet with disc magnet
    [dengineering_v01.1.scad, dengineering_v01_1.stl, dengineering_v01_2.stl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]
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2023-06-26 fixed issue with pins not lining up exactly right, made it so magnets actually touch at the surface, edited jig, printed 4 iterations ref issue#2
    [dengineering_v02.3.1.stl, dengineering_v02.3.2.stl, dengineering_v02.3.3.stl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]
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2023-07-15 corrected comments to align with documentation (SCAD) #2
    [dengineering_v02.3.9.stl, dengineering_v02.3.scad]
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2023-07-15 fixed BOM and vendor list
    [Magnet_and_PP_Vendor_List.ods]
2023-09-13 I edited the BOM to add the materials I'm using for the latest version of the prototype version 3. * Switching from disks to cube magnets allows for superior assembly, greater surface area connection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
    [Magnet_and_PP_Vendor_List.ods, dengineering_v02.3.scad]
2023-09-13 issue #2 - start new prototype scad file, update BOMs, update vendor list
    [Magnet_and_PP_Vendor_List.ods, usbamagb_v03.scad]
2023-09-18 updated code for magnets and started work creating an enclosure. #issue2
    [usbamagb_v03.scad]
2023-09-18 moved enclosures near their faces and added color issue #2
    [usbamagb_v03.scad]
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2023-09-18 issue #2 updating enclosure code
    [usbamagb_v03.scad]
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2023-09-18 made the wire jigs proper reflections of each other and thinner issue #2
    [usbamagb_v03.scad]
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2023-09-18 Printed the last iteration, yay! Made adjustments to this file accordingly. Created separate enclosure_r and enclosure_b to better accomodate the needs of the enclosure_b, which needed a larger outle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
    [usbamagb_v03.scad]
2023-09-19 increase magnet tolerance (magnets broke piece during press fit) and increase length of breakaway again (needs the same if not more room than release piece
    [usbamagb_v03.1.stl, usbamagb_v03.scad]
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2023-09-19 adjusted holes in lid issue #2
    [usbamagb_v03.scad]
2023-09-19 fixing up the lid/ support posts issue #2
    [usbamagb_v03.scad]
2023-09-22 fixed lid issue #2
    [usbamagb_v03.3.stl, usbamagb_v03.4.stl, usbamagb_v03.scad]
2023-09-23 actually fixed lid this time issue #2
    [usbamagb_v03.4.stl, usbamagb_v03.scad]
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2023-09-23 fixed a quick thing before getting this version ready to print
    [usbamagb_v03.scad]
2023-09-23 latest version of case issue #2
    [usbamagb_v03.5.stl]
2023-09-23 fixed a couple more minor issues with the jig slot and lid holes
    [usbamagb_v03.5.1.stl, usbamagb_v03.scad]
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2023-09-24 Commented out the code that made the fancy curved wire jig- straight jig is in, now... separated buskill logo into two parts for neat logo completion when mated. changed colors to red blue because I'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
    [usbamagb_v03.scad]
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2023-09-24 oops I had the kill flipped the wrong way. fixed and providing latest version of stl issue#2
    [usbamagb_v03.6.stl, usbamagb_v03.scad]
2023-09-24 oops actually fixed buskill logo this time
    [usbamagb_v03.6.stl, usbamagb_v03.scad]
2023-10-02 small adjustments to the faces and removing files accidentally added to hte repo issue#2
    [usbamagb_v03.7.stl, usbamagb_v03.scad]
2023-10-04 lengthened breakaway (blue) case, increased height of face to match with case, corrected some parametric variable values and names issue#2
    [usbamagb_v03.8.stl, usbamagb_v03.scad]
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2023-10-07 corrected introductory instructions, grouped code more logically and added sections, begin outline of assembly section issue #2
    [usbamagb_v03.scad]
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2023-10-07 you can now use the assembly section of the code to only print release, only print breakaway, only print faces, or only print jigs, however you need issue #2
    [usbamagb_v03.scad]
2023-10-07 trying to correct some issues with face mating. will know if it worked after print test. issue#2
    [usbamagb_v03.scad]
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2023-10-10 added some stability walls outside the pogo receptor admission for more stable face mating. issue #2
    [jig_v03.9.stl, usbamagb_v03.scad]
2023-10-10 adding some STLs to the repo for ya issue #2
    [breakaway_v03.9.stl, cubeface_v03.9.stl, discface_v03.9.stl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]
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2023-12-09 Update README.md
    swap out image of goldfishlaser version case
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2024-01-07 adjusted void for cube magnet created stl for breakaway, release, and both. #issue2
    [breakaway_v03.9.1.stl, release_v03.9.1.stl, usbamagb_v03.9.1.stl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]
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2024-03-17 working on new version correcting for issues in the connection and wall thickness
    [usbamagb_v03.1.scad, usbamagb_v03.9.3.stl]
2024-06-16 scad version 3.1b hosts changes to swap release and breakaway face. the depth of the pogo pin house is increased and the stl is version 3.9.4 #issue2
    [usbamagb_v03.1b.scad, usbamagb_v03.9.4.stl]
2024-06-16 corrected typo in vendor list notes and added pogo pin data sheet
    [Magnet_and_PP_Vendor_List.ods]
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2024-06-17 refining enclosure code... issue#2
    [usbamagb_v03.1b.scad]
2024-06-17 refine jig slot issue#2
    [usbamagb_v03.1b.scad]
2024-06-17 fixed a couple mistakes issue#2
    [usbamagb_v03.1b.scad, usbamagb_v03.9.4.stl]
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2024-06-18 changes for jig, add wire holder issue#2
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2024-06-19 bring holes closer on jig2 #issue2
    [usbamagb_v03.1b.scad, usbamagb_v03.1b.stl]
2024-06-19 changes relating to trying to improve face mating. hypothesis is give the pogo pins a bit more room and maybe there will be less force but still a good connection. issue#2
    [usbamagb_v03.1b.scad, usbamagb_v03.1b.stl]
2024-06-19 fixing lid and holes in lid issue#2
    [usbamagb_v03.1b.scad, usbamagb_v03.1b.stl]
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2024-06-22 breakaway could probably be a little smaller lets see issue#2
    [usbamagb_v03.1b.scad, usbamagb_v03.1b.stl]
2024-06-22 forgot to move kill.svg over a tad whoopsiedaisy issue#2
    [usbamagb_v03.1b.scad, usbamagb_v03.1b.stl]
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2024-07-19 now all the release stuff is with release and breakaway with breakaway, all the parts are level on 0, removed deprecated content, corrected assembly section, shrunk enclosure #2
    [usbamagb_v04.0.scad, usbamagb_v04.0.stl]
2024-07-19 had accidentally who knows what but fixed release face
    [usbamagb_v04.0.scad, usbamagb_v04.0.stl]
2024-07-19 quick fix for jigs #2
    [usbamagb_v04.0.scad, usbamagb_v04.0.stl]
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2026-03-09 adding permissions to unicode detection workflow yaml
    This commit updates the unicode_warn CI workflow to include write
    permissions on issues and pull-requets, to allow the bot to drop a
    comment in PRs as to wheather or not there's been some (potentially
    malicious) unicode detected in the given PR.
    For more info, see:
    * https://github.com/BusKill/usb-a-magnetic-breakaway/issues/16
    * https://github.com/BusKill/usb-a-magnetic-breakaway/pull/15
    * https://github.com/maltfield/detect-malicious-unicode/blob/47238a684a6036bf13c3516a71b749886e0c8c33/.github/workflows/unicode_warn.yml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
    * https://tech.michaelaltfield.net/bidi-unicode-github-defense/
2026-05-12 add step CAD file for USB-C version of injection molded component
    This commit adds a new STEP file that we got today for the USB-C version
    of the cable, which we'll be selling on our website soon.
    I also did some cleanup: FreeCAD makes backup files named FCStd1. Those
    are redundant, so I deleted them. And I also setup a .gitignore file to
    prevent those from getting added in the future. And I updated the git
    config to ignore-case on those files (since they could be .FCStd1 or
    .fcstd1).
    TODO: convert the STEP file to FreeCAD. Add the coupler. And colorize
    it.
    [4Pin_2.54mmPH_runway_magnetic_connector_TYPEC.stp]
2026-05-12 adds CAD for magnetic coupler
    This commit adds a FreeCAD file for just 'AS-BKA-CUP-001' -- which is a
    non-complete product, only containing the magnetic coupler (not the
    cable) to which the USB device (eg thumb drive) plugs into.
    Note that this differs a bit from some of the (very outdated) CAD files
    in this repo -- namely because the size was wrong in the earlier
    versions. When it actually came to putting the parts together, the
    overmold was a bit longer (~27 mm) than the original concept design
    (~20 mm).
    TODO: update the other CAD files with this "real sized" object. And use
    it to make the USB-Type-C variant
    [AS-BKA-CUP-001.FCStd]
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2026-05-13 added CAD for AS-BKC-CAB-001 product
    This commit adds the CAD file for the AS-BKC-CAB-001 SKU product that
    we'll be selling soon.
    I created this by taking the AS-BKA-CAB-001 product and modifying it by
    just replacing the tip with one of the colorized STEP file.
    The cable is 1-meter, which is what we sell -- but it's not great for
    visualizations (eg in marketing material), so I might want to make one
    that's much shorter -- for visual purposes.
    After multiple attempts, I couldn't figure out how to reset the "origin"
    of the USB-C tip, so the "transform" arrows were annoyingly far away
    from the actual object -- making it a pain to position into place. So
    that would be a nice-to-have TODO on t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
    [AS-BKC-CAB-001.FCStd]
2026-05-14 added new file with short version of AS-BKC-CAB-001
    This commit adds a version of our USB-C BusKill Cable with a comicly
    short cable (~58 mm). This is not a product we make, nor would it be
    recommended -- but it is useful as a visual aid for the purposes of
    documentation and marketing.
    I'm currently writing an article about the release of our new USB Type-C
    cable, and I'll be using a screenshot of this CAD in the Featured Image
    [AS-BKC-CAB-001_short.FCStd]
2026-05-14 simplify AS-BKC-CAB-001_short.FCStd
    This commit simplifies the CAD file for our "marketing" version of a
    "comicly short" USB Type-C BusKill Cable.
    I shortend the cable by drawing a huge plane and then cutting it with
    the Part workbench "Make a cut of two shapes". The result was literally
    thousands of different shapes, which I then had to delete (at great
    expense of my poor CPU).
    The last commit still had the memory of that plane and cut, so this
    commit made a copy of it with Part -> Create a Copy -> Make a Simple
    Copy.
    This reduced the (compressed) file size from 916K to 696K. Here's the
    current tree of (uncompressed) sizes, per:
    * https://www.eco-libre.org/big-freecad-file-size/
    -----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
    [AS-BKC-CAB-001_short.FCStd]
